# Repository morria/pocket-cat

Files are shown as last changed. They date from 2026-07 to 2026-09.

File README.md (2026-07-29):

# Pocket Cat

Control your HF transceiver from an iPhone. Pocket Cat is a small
BLE↔USB bridge — a Seeed XIAO ESP32-S3 plugged into the radio's USB CAT
port — plus a Swift library (`CATBridgeKit`) that gives iOS apps a typed,
observable model of the rig: frequency, mode, PTT, RF power, a catalog of
rig settings (gains, squelch, keyer speed, NB/NR, preamp, attenuator,
filter width …), and Yaesu menu items, over Bluetooth LE — with raw CAT
kept only as an escape hatch.

Built for portable operation: radios like the FT-891 have full CAT
control but no Bluetooth. Pocket Cat adds it without putting any radio
logic in the firmware.

## Supported radios

| Radio | CAT dialect | USB interface |
|---|---|---|
| Yaesu FT-891 | Yaesu ASCII (`;`-terminated) | CP2105 dual UART |
| Yaesu FTX-1 | Yaesu ASCII (`;`-terminated) | CP210x/CDC (confirmed at bring-up) |
| QRP Labs QMX | Kenwood TS-480 subset | Native CDC-ACM |

## How it works

```
iOS app ──(SwiftUI/@Observable)── CATBridgeKit
                                      │  BLE GATT (bonded, encrypted)
                              XIAO ESP32-S3 bridge
                                      │  USB host (CDC-ACM / CP210x)
                                   radio CAT port
```

**The bridge is a dumb pipe.** The firmware enumerates the radio over USB
host, shuttles bytes between USB and BLE, and exposes a small control
channel (baud, link state, radio identity, failsafe). All CAT protocol
knowledge — command encoding, response parsing, polling, state modeling —
lives in `CATBridgeKit`. New radio support is a Swift change; the firmware
doesn't care.

An app's complete state-and-control loop:

```swift
import CATBridgeKit

let central = CATBridgeCentral()
let bridge = await central.bridges().first { _ in true }!
let session = try await central.connect(to: bridge) // pairs, probes baud,
                                                    // picks dialect, arms failsafe
Text(session.state.frequency?.description ?? "—")   // bind UI to state
try await session.set(frequency: 14_074_000)        // send commands
```

Because the BLE link can key a 100 W transmitter, the release firmware
requires LE Secure Connections bonding before accepting any CAT or control
writes, and a dead-man failsafe drops PTT if the link goes quiet.

## Build one

**[`BUILD.md`](BUILD.md) is the start-to-finish walkthrough** — prerequisites,
what to buy, printing, flashing, soldering, assembly, and installing the app,
with a checkpoint at every stage so you know each step worked before starting
the next. The reference detail lives alongside the thing it describes:

| For | See |
|---|---|
| Parts, tools, and where to buy them | [`BOM.md`](BOM.md) |
| Printing, assembly, adjusting the fit | [`enclosure/README.md`](enclosure/README.md) |
| Firmware build / test / flash | [`esp32s3/README.md`](esp32s3/README.md) |
| FT-891 app build / test / install | [`ios/pocket-cat-ft891`](ios/pocket-cat-ft891) |
| QMX app build / test / install | [`ios/pocket-cat-qmx`](ios/pocket-cat-qmx) |
| FTX-1 app build / test / install | [`ios/pocket-cat-ftx1`](ios/pocket-cat-ftx1) |

A unit is a XIAO ESP32-S3 (the version with the U.FL antenna connector — there
is no onboard antenna), a 602535 LiPo cell, a TPS61023 boost module to feed
5 V back to the radio, an SS12F15G5 slide switch, one M3 bolt and nut, and two
printed parts — about 23 g of PETG. You also need a **USB-to-UART dongle** to
flash, since the XIAO's own USB-C port is occupied by the radio.

The case is IP00: open USB aperture, open switch slot, unsealed parting line.
Bag and bench use.

## The apps

**[FT-891](ios/pocket-cat-ft891)** — operate (frequency, mode, band, meters,
RF power, tuner, split/clarifier, hold-to-talk PTT), all 159 menu items in
plain English, and profiles that capture the radio's full configuration to
iCloud Drive and diff it against the live rig.

**[FTX-1](ios/pocket-cat-ftx1)** — the FT-891 surface extended for a
full-mode SDR: every newcat mode including C4FM and DATA-FM, a CW keyboard
driving the radio's memory keyer, and raw `EX` menu access with your own
bookmarks.

**[QMX](ios/pocket-cat-qmx)** — operate (four modes plus sideband, RIT, split,
keyer), the radio's **entire menu tree** discovered live over the QMX `MM`/`ML`
Menu Manager with a written explanation for every item, and
save/load-everything profiles.

Both include a full simulator, so the whole app runs with no hardware at all.

## Using the library

Add as a Swift Package dependency (iOS 17+ / macOS 14+):

```swift
.package(url: "https://github.com/morria/pocket-cat.git", from: "1.0.0")
```

then `import CATBridgeKit`.

## Repository layout

```
esp32s3/            bridge side
  firmware/         ESP-IDF (≥5.2) project for the XIAO ESP32-S3
  test/host/        C unit + end-to-end simulation suites (gcc, ASan/UBSan)
  test/tools/       radio_sim.py, ble_client.py, soak.py bench tools
  docs/             implementation plan, BLE protocol spec (normative)
Package.swift       Swift package manifest (swift-tools 6.0; iOS 17 / macOS 14)
Sources/            CATBridgeCore (pure logic) + CATBridgeBLE (CoreBluetooth)
Tests/
BUILD.md            start-to-finish build walkthrough
ios/
  pocket-cat-ft891/ FT-891 iOS app — FT891Kit (menu catalog, profiles,
                    simulator) + FT891UI (SwiftUI) + xcodegen app shell
  pocket-cat-qmx/   QMX iOS app — QMXKit (MM/ML menu client, profiles,
                    simulator) + QMXUI (SwiftUI) + xcodegen app shell
  pocket-cat-ftx1/  FTX-1 iOS app — FTX1Kit (Yaesu commands, passband,
                    memories) + FTX1UI (SwiftUI) + xcodegen app shell
BOM.md              bill of materials for one unit
enclosure/          3D-printable case — pocket_cat_case.scad + base/lid STLs,
                    with printing and assembly instructions
docs/               system-level reports + library implementation plan
```

## Testing

```sh
make -C esp32s3/test/host run            # C suites: unit + e2e simulation
python3 -m pytest esp32s3/test/tools -q  # codec, radio_sim, pty rig tests
swift test
```

The BLE wire format is pinned by a golden vector file byte-compared across
the firmware and Swift codebases in CI. Hardware-in-the-loop bench tools
(`radio_sim.py`, `ble_client.py`, `soak.py`) are described in
`esp32s3/docs/implementation.md` §7.

## Status

All layers build and pass CI (ESP-IDF v5.3 target build, 57 C tests,
32 Python tests, 56 Swift tests), and the firmware runs on real XIAO
ESP32-S3 hardware — advertising, bonding policy, and the status channel
verified over the air. Radio bring-up (FT-891 first) is next; see
[`docs/completeness-report.md`](docs/completeness-report.md) for exactly
what is and isn't yet proven on hardware.

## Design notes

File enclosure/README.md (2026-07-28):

# PocketCAT — enclosure

A two-part printed enclosure for a battery-powered Bluetooth-to-CAT
adapter. It holds a Seeed XIAO ESP32S3, a 602535 LiPo cell, a flat FPC
antenna, a slide switch, and a TPS61023 boost module that supplies 5 V to
the USB device attached to the XIAO.

**Closed size: 59.2 × 47.2 × 18.9 mm.** Two printed parts, one bolt, one
nut.

---

## Files

| File | Description |
|---|---|
| `pocket_cat_base.stl` | Base — cell bay, antenna bay, switch mount, bolt boss |
| `pocket_cat_lid.stl` | Lid — board pocket, boost cradle, captive nut boss |
| `pocket_cat_case.scad` | Parametric source, OpenSCAD customizer ready |
| `BOM.md` | Bill of materials |
| `WIRING.md` | Wiring diagrams and connection tables |

The `.scad` is the source of truth; both STLs are generated from it:

```
openscad -o pocket_cat_base.stl -D 'part="base"' pocket_cat_case.scad
openscad -o pocket_cat_lid.stl  -D 'part="lid"'  pocket_cat_case.scad
```

---

## Bill of materials

| Item | Notes |
|---|---|
| Seeed XIAO ESP32S3 | 17.7 × 21.1 mm, USB-C overhanging 2.9 mm |
| 602535 LiPo, 3.7 V 500 mAh | 25 × 37 × 6 mm pouch cell |
| FPC antenna, 37 × 18 mm | With U.FL pigtail |
| SS12F15G5 slide switch | SPDT, 19.8 mm frame, ⌀2.2 holes, 3 × 3 × 5 mm knob |
| TPS61023 boost module | 17.8 × 11.3 mm, header **not** fitted |
| M3 × 10 hex socket head bolt | ×1 |
| M3 nut | ×1 |
| 26 AWG stranded wire | ~60 mm per run |

---

## Layout

The interior is divided lengthwise by a 7 mm rib. Heavy items sit in the
base; the two circuit boards mount to the lid and lift out with it.

**Base, left bay — 27 × 39 × 7.0 mm.** The cell lies flat on the floor
against a backstop rib at the far end. There is 1.0 mm of clearance above
it for pouch swelling; nothing should be packed into that space.

**Base, right bay — 22 × 39 mm.** Empty apart from the slide switch on
its outer wall. The width is set by the span the lid needs for the
antenna, not by anything in the base.

**Base, right wall.** Two slide switches, centred at y 12.6 and y 34.6.
Each has its own peg pair on 14.4 mm centres and a 6.4 × 3.6 mm actuator
slot. S1 is the master on/off; S2 selects run or charge. A local 1.2 mm relief
in the lid skirt above the switch gives the frame room.

The pegs are deliberately unequal. One is round at ⌀1.90; the other is a
lozenge, 2.00 mm across the pitch axis but only 0.90 mm along it. The
round peg locates the switch and the lozenge holds its angle while
letting hole-spacing error float out. Together they absorb **±0.80 mm**
of pitch variation, against the ±5 % (±0.72 mm) these switches are made
to. Both taper at the tip for a square start and have 0.15 mm shaved off
their undersides to compensate for print sag.

**Divider rib.** Carries the bolt boss, and has a notch through its top
edge at each switch centreline, y 12.6 and y 34.6, for the switch
wiring.

**Lid, board pocket — 18.0 × 21.4 mm.** The XIAO sits component-side
down, USB-C pointing into the wall aperture. Two ramped tabs per side
retain it. The whole pocket floor is relieved 1.2 mm, giving 2.8 mm of
clearance over the BAT+/BAT− solder joints.

**Lid, wire channel.** A 3.0 mm gap through both pocket ribs at
y 12.6–15.6, with a matching groove in the lid, forms a 2.6 mm tall route
for the battery leads to leave the board pocket. Cut on both sides — use
whichever suits your pad positions.

**Lid, boost cradle — 18.8 × 12.3 mm.** Ribs 1.6 × 2.5 mm locate the
module on all four sides, with a 10 mm opening in the pad edge for
soldering access and a 0.5 mm lead-in chamfer at the mouth. The ribs are
a deliberately loose fit — 0.5 mm per side — so the module drops in
squarely. The bay clears modules up to 7.5 mm thick.

A compliant retention finger at each end snaps the module down. Each is
1.0 mm thick, hangs 4.2 mm below the lid and sits in its own relief slot
so it flexes independently. They stand at the board's nominal edge rather
than at the rib, so clearance and grip are set separately: the ribs stay
loose for easy insertion while the fingers alone do the holding.

The retaining face is a **wedge rather than a square shoulder**, so it
grips any PCB from 0.6 to 1.8 mm thick without knowing the thickness in
advance. Overlap onto the board is 0.21 mm at 1.0 mm thickness, 0.39 at
1.2 and 0.76 at 1.6. The finger's spring preloads the module against the
lid.

**Lid, boost-to-board channels.** Two 3.5 mm openings through the pocket
end stop at x 10.6–14.1 and 16.1–19.6, separated by a 2 mm web. They cut
below the board only (z 10.7–13.3), so the stop stays solid at board
level and still blocks the PCB's rear edge. These carry the boost 5V and
GND leads into the pocket; the web keeps the pair separated.

The battery-to-boost run needs no channel — the space between the cell
top and the lid is open the whole way, and the leads rise straight into
the cradle's 10 mm pad-edge gap.

**Lid, antenna recess — 18.4 × 37.4 × 0.4 deep.** The FPC adheres to the
lid inner face, in a shallow recess between the nut boss and the skirt.
Mounting it here rather than in the base keeps the whole RF path on one
part: the pigtail never crosses the parting line, so opening the case
does not flex the U.FL connector. It also puts the switch frame 7 mm
below the antenna instead of 1.1 mm above it.

**Lid, pigtail exit.** A full-height gap through both pocket ribs at
y 20.9–23.5, at the far end of the board from the USB-C. It runs below
the board only, so the lid keeps full thickness there. Two ⌀1.8 guide
posts at x 34.0 form a 1.6 mm channel carrying the pigtail past the nut
boss on its way to the antenna.

**Lid, wire anchors.** Two ⌀2.0 posts hanging 4.0 mm from the lid form a
**3.6 mm channel**, set 0.65 mm clear of the board pocket rib, sized for two 22 AWG silicone leads side by side.
They take strain off the BAT+/BAT− pads, which are surface pads with no
through-hole anchorage and lift if a lead is pulled.

---

## Fastener

A single M3 enters from the **underside**, its head fully recessed in a
⌀6.2 × 3.0 counterbore flush with the bottom face. It passes up through a
stub on the divider rib and threads into a nut held captive in a boss
under the lid. Nothing protrudes from either outer face.

The nut pocket sits at z 10.6–13.1 with 3.0 mm of material above it and
loads through a slot on the antenna-bay side. An M3 × 10 engages 2.4 mm
of thread; an M3 × 12 also fits.

Tighten snug only. The skirt engages 7.5 mm around the full perimeter and
carries the shear; the bolt only resists lift.

---

## Key dimensions

| Feature | Value |
|---|---|
| Cell bay | 27 × 39 × 7.0 mm |
| Antenna recess (lid) | 18.4 × 37.4 × 0.4 deep |
| Board pocket | 18.0 × 21.4 mm |
| Clearance over BAT pads | 2.8 mm |
| USB-C aperture | 9.6 × 3.8 mm, at z 9.8–13.6 |
| Switch slot | 6.42 × 3.62 mm |
| Panel markings | 3.5 mm tall (triangle 4.4), 0.9 stroke, 0.5 deep |
| Wire anchor channel | 3.6 mm wide × 4.0 deep |
| Pigtail exit gap | y 20.9–23.5, full rib height |
| Pigtail guide channel | 1.6 mm |
| Boost-to-board channels | 2 × 3.5 mm, below the board |
| Peg pitch | 14.4 mm, ±0.80 mm absorbed, 2 pairs |
| Boost cradle | 18.8 × 12.3 mm, 7.5 mm depth clearance |
| Boost PCB grip range | 0.6 – 1.8 mm |
| Wall / floor / lid | 1.6 / 1.6 / 2.8 mm |

---

## Printing

- PETG, 0.4 mm nozzle, 0.2 mm layer, 4 walls, 25 % infill
- **No supports.** The USB aperture is split across the parting line, and
  every hole either opens downward or bridges under 18 mm.
- Base prints floor down; lid prints top face down, as exported
- The switch pegs print as horizontal features and sag slightly on their
  undersides. Dress them with a blade before fitting the switch.

---

## Assembly

**Prepare**

1. Clean the two switch pegs until the frame drops on without forcing.
   Take material off the undersides first — that is where sag collects.
2. Slide the M3 nut into the lid boss through the slot on the
   antenna-bay side. A dab of glue makes it permanent.

**Base**

3. Fit the slide switch onto the posts, actuator through the slot, and
   glue.
4. Lay the cell in the left bay against its backstop. Do not glue it, and
   do not fill the 1.0 mm space above it. If it rattles, lay a strip of
   Kapton across it and stick that to the bay walls, not to the pouch.

**Lid**

6. Wipe the lid antenna recess with IPA and adhere the FPC. PETG is a
   poor adhesive substrate — abrade it lightly if the bond feels weak.
7. Fit the XIAO: connector into the aperture first, then press the rear
   edge up past the retention ramps.
8. Route the U.FL pigtail out of the board pocket through the gap at
   y 20.9–23.5 and through the guide posts at x 34.
9. Press the boost module into its cradle with the pad edge facing the
   board, until both end fingers snap over it.

**Wiring** — work with the halves side by side, and allow **60 mm** per
run so the lid can lie flat during service.

9. Cut the JST plug off the cell. Solder its leads to BAT+ and BAT− on
   the underside of the XIAO, bend the wires flat immediately, and put a
   blob of hot glue over the joint. Those pads lift if a wire is tugged.
10. Wire cell + to the switch common, and the switched output to both the
    XIAO BAT+ and the boost Vin. Switching off then kills the boost as
    well, so its output cannot fight a host's VBUS when a PC is plugged
    into the USB-C port to reflash.
11. Wire cell − to boost GND.
12. Wire boost 5V and GND to VUSB and GND on the XIAO, passing them
    through the two channels in the end stop — one lead per channel.
    Twist both the input and output pairs tightly; loop area is what
    radiates.
13. Check whether En has a pull-up on your boost module. If not, tie it
    to Vin.

**Close**

14. Dress the battery leads out through the wire channel and hook them
    through the anchor posts.
15. Route the boost leads forward along the gap at x 25.3–28.6 to reach
    the wire channel.
16. Lower the lid — the skirt slides inside the base walls — then fit the
    M3 from underneath and snug it.

---

## Adjusting the fit

Open the `.scad` in OpenSCAD and use View → Customizer. Everything is a
named parameter.

| If | Change |
|---|---|
| The lid is tight or loose | `skirt_gap` |
| The board is tight or loose | `pcb_fit_x`, `pcb_fit_y` |
| The board needs more or less retention | `lip` |
| The switch pegs are tight or loose | `post_d`, `post2_d`, in 0.05 steps |
| The pegs will not reach both holes | `post2_y` — narrower absorbs more |
| The switch actuator binds | `sw_travel` — set to your measured throw |
| The on/off markings are the wrong way round | `mark_flip` |
| The switch sits high or low | `sw_cz` |
| The cell measures over 6 mm | `bat_z`, or `bat_swell` for headroom |
| The boost module is a different size | `boost_l`, `boost_w` |
| The boost fingers grip loosely or not at all | `boost_wedge`, `boost_tab_off` |
| The boost pocket is tight or loose | `boost_fit` |
| The wire anchors are tight for your gauge | `anchor_gap`, `anchor_h` |
| The U.FL sits at the other end of the board | `coax_y0`, `coax_y1` |
| The boost-to-board channels are tight | `endch_w`, `endch_gap` |

---

## Limitations

No gasket, an open USB aperture, an open switch slot, an unsealed parting
line: this is IP00. Bag and bench use only.

The switch frame and the boost module both sit above the antenna bay
region, and the case has no shielding. If the boost's switching noise
raises your HF noise floor, fit a ferrite on the USB lead and consider
lining the lid over the boost with copper tape bonded to battery
negative.

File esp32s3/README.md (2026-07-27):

# Pocket Cat — ESP32-S3 BLE↔USB CAT Bridge

Pocket Cat firmware for a Seeed XIAO ESP32S3 that bridges a BLE central (iOS app) to a
transceiver's USB CAT interface (Yaesu FT-891, Yaesu FTX-1, QRP Labs QMX).
The ESP32 is a transparent byte pipe; all CAT protocol logic lives on the
remote. See [`docs/implementation.md`](docs/implementation.md) for the full
design and [`docs/protocol.md`](docs/protocol.md) for the BLE contract.

## Layout

```
firmware/            ESP-IDF (≥5.2) project
  main/              app wiring, bridge task, LED
  components/
    ctrl_proto/      BLE control-channel TLV codec       (pure C, host-tested)
    cat_bridge/      rings, coalescer, detect, core      (pure C, host-tested)
    usb_link/        usb_host + CDC-ACM/CP210x glue
    ble_link/        NimBLE GATT server
test/
  host/              unit + end-to-end simulation suites (gcc + ASan/UBSan)
  tools/             radio_sim.py, ble_client.py, soak.py, catproto.py
docs/                implementation plan, protocol spec, references/
```

## Prerequisites

- **ESP-IDF ≥ 5.2** (CI builds against 5.3) — install per
  [Espressif's getting-started guide](https://docs.espressif.com/projects/esp-idf/en/stable/esp32s3/get-started/).
  Every new shell needs `. $HOME/esp/esp-idf/export.sh`.
- **Python 3** with `pytest pytest-timeout pyserial`, for the tools tests.
- **A USB-to-UART dongle with 3.3 V logic** (CP2102, CH340, FT232) to flash.
  A 5 V-only dongle will damage the board.

Verify with `idf.py --version`.

## Build

```sh
cd firmware
idf.py set-target esp32s3      # once per checkout
idf.py build
```

## Test

Both suites are host-side and need no hardware:

```sh
make -C test/host run              # C: unit + e2e simulation (ASan/UBSan)
python3 -m pytest test/tools -q    # Python: codec, radio_sim, pty rig
```

Both must exit 0. CI runs exactly these on every push.

## Flash

**The native USB-C port cannot be used for flashing** — it runs in host mode
for the radio. Console and bootloader are on UART0, so wire the dongle to the
board first. Note that TX goes to RX:

| Dongle | XIAO ESP32-S3 |
|---|---|
| TX | GPIO44 (RX) |
| RX | GPIO43 (TX) |
| GND | GND |

```sh
idf.py -p /dev/tty.usbserial-XXXX flash monitor    # macOS
idf.py -p /dev/ttyUSB0 flash monitor               # Linux
```

Find the port with `ls /dev/tty.usb*` or `ls /dev/ttyUSB*`. If flashing won't
start, hold **BOOT**, tap **RESET**, release BOOT to enter the ROM downloader,
then run the command again.

Flash **before** the board goes into the enclosure — it mounts component-side
down and the pads become awkward to reach (see [`../BUILD.md`](../BUILD.md)).

VBUS must be supplied to the radio — measure the 5V↔VBUS net first
([`docs/references/hardware-xiao-esp32s3.md`](docs/references/hardware-xiao-esp32s3.md)).

Debug build without BLE bonding (bench only — LED triple-blinks):
`idf.py menuconfig` → CAT Bridge BLE → uncheck "Require LE encryption".

**Working:** `idf.py monitor` shows the bridge booting and it advertises as
`CATBridge-XXXX` in any BLE scanner.

Hardware-in-the-loop (docs §7.3/§7.4): run `radio_sim.py` on a CP2105/CP2102/
CDC fixture attached to the ESP32's USB port, and drive BLE with
`ble_client.py` (`status`, `cat "FA;"`, `echo`, `storm`) and `soak.py`.
CI builds the firmware (ESP-IDF v5.3) and runs every host suite on each push.

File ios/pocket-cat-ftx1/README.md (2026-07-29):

# Pocket Cat FTX-1

Native iOS control for the Yaesu FTX-1 over the [Pocket Cat](../..) BLE↔USB
CAT bridge. SwiftUI, iOS 17+.

- **Operate** — frequency (digit-drag tuning, direct entry), full mode set,
  band bar with band-stacking, S/PO/SWR/ALC meters, RF power, antenna-tuner
  cycle, split/clarifier/VFO ops, the passband strip, hold-to-talk PTT
  (failsafe-interlocked).
- **CW** — type and the radio's memory keyer sends it, with station
  templates and an on-air time estimate.
- **Menu** — raw `EX` access by number, with bookmarks you build yourself.
- **Memories** — saved channels and automatic recents, kept on the device.

A built-in simulator (Connection → Simulated FTX-1) runs the whole app with
no hardware.

Built from the [FT-891 app](../pocket-cat-ft891): the FTX-1 speaks the same
modern Yaesu ASCII dialect, so the operate surface, passband strip, band
memories and connection plumbing carry straight over
(`esp32s3/docs/references/yaesu-cat-ftx1.md`).

## What differs from the FT-891 app

- **Full mode set.** The FTX-1 is a full-mode SDR, so the newcat codes the
  FT-891 leaves unused are live: `A` DATA-FM, `E` C4FM, `F` DATA-FM-N.
- **CW keyboard.** Send-only, and the screen says so — a Yaesu has no
  command that hands decoded CW back, which is why the QMX app has a live
  transcript and this doesn't.
- **Menu by number, not by catalog.** The FT-891 app ships a typed catalog
  of its 159 items. The FTX-1's numbering differs and this repo has no
  verified catalog for it, so the Menu tab reads and writes raw `EX` digits
  and lets the radio judge them. A borrowed catalog would confidently write
  the wrong setting.
- **No profiles yet.** Capture/diff/apply is built on that catalog, so it
  returns when there is one.

## Layout

```
Package.swift        FTX1Kit (radio semantics) + FTX1UI (SwiftUI)
Sources/FTX1Kit/     command wrappers, passband, band memories, CW text and
                     timing, station settings, simulator, RigController
Sources/FTX1UI/      Operate / CW / Menu / Connection views
App/                 xcodegen shell (project.yml) for the iOS app target
Tests/FTX1KitTests/  sim-driven integration, passband, memories
```

## Prerequisites

Xcode 15+, and `xcodegen` (`brew install xcodegen`) to generate the app
project. Nothing else to clone: this package lives inside the Pocket Cat
repo at `ios/pocket-cat-ftx1` and depends on the root package
(`CATBridgeKit`) by the relative path `../..`.

## Test

```sh
swift test          # headless: FTX1Kit + full sim integration, no hardware
```

## Build and run

```sh
cd App && xcodegen generate      # creates FTX1.xcodeproj
open FTX1.xcodeproj              # run the FTX1App scheme
```

Set your own signing team in Xcode (target → Signing & Capabilities); find
the ID with:

```sh
security find-certificate -c "Apple Development" -p |
  openssl x509 -noout -subject | tr ',' '\n' | grep OU
```

## Install on a device

```sh
xcrun devicectl list devices
xcodebuild build -project FTX1.xcodeproj -scheme FTX1App \
  -destination 'id=YOUR-DEVICE-ID' -derivedDataPath build \
  -allowProvisioningUpdates
xcrun devicectl device install app --device YOUR-DEVICE-ID \
  build/Build/Products/Debug-iphoneos/FTX1App.app
```

If signing fails on the iCloud entitlement, build with
`CODE_SIGN_ENTITLEMENTS=FTX1App/FTX1App-NoCloud.entitlements`.

## Not yet confirmed on hardware

The FTX-1 has not been through bring-up. Per
`esp32s3/docs/references/yaesu-cat-ftx1.md` its USB descriptor **is**
confirmed — a CP2105 behind an internal hub — but its `ID;` response code is
not, and neither is which of the dual UARTs is Enhanced. The app works
through the bridge's generic Yaesu profile regardless.

The passband strip's `IS`/`SH`/`BP`/`CO` formats are inherited from the
FT-891 family rather than verified on an FTX-1, and the simulator answers
`ID;` with the FT-891's code as a placeholder. Both want checking against a
real rig before they are trusted.

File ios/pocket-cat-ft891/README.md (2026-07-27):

# FT-891 Pocket

Native iOS control for the Yaesu FT-891 over the
[Pocket Cat](../..) BLE↔USB CAT bridge. SwiftUI, iOS 17+.

- **Operate** — frequency (digit-drag tuning, direct entry), mode, band,
  S/PO/SWR/ALC meters, RF power, antenna-tuner cycle, split/clarifier/VFO
  ops, hold-to-talk PTT (failsafe-interlocked).
- **Settings** — all 159 FT-891 menu items with plain-English names and
  descriptions, searchable, editable over CAT (`EX`).
- **Profiles** — capture the radio's full configuration to a JSON file in
  iCloud Drive; diff any profile against the live radio and apply the
  changes with per-item confirmation.

A built-in FT-891 simulator (Connection → Simulated FT-891) runs the whole
app with no hardware.

## Layout

```
Package.swift        FT891Kit (radio semantics) + FT891UI (SwiftUI)
Sources/FT891Kit/    menu catalog (159 items), FT-891 command wrappers,
                     profile engine/store, simulator transport, RigController
Sources/FT891UI/     Operate / Settings / Profiles / Connection views
App/                 xcodegen shell (project.yml) for the iOS app target
Tests/               codecs, catalog↔docs checker, sim-driven integration
docs/                CAT + menu references, research, fun-feature backlog
PLAN.md              design/implementation/test plan
```

## Prerequisites

Xcode 15+, and `xcodegen` (`brew install xcodegen`) to generate the app
project. Nothing else to clone: this package lives inside the Pocket Cat
repo at `ios/pocket-cat-ft891` and depends on the root package
(`CATBridgeKit`) by the relative path `../..`.

## Test

```sh
swift test          # headless: FT891Kit + full sim integration, no hardware
```

## Build and run

```sh
cd App && xcodegen generate      # creates FT891.xcodeproj
open FT891.xcodeproj             # run the FT891App scheme
```

Regenerate whenever `project.yml` changes; the `.xcodeproj` is not tracked.

Set your signing team in Xcode (target → Signing & Capabilities). Find your
team ID with:

```sh
security find-certificate -c "Apple Development" -p |
  openssl x509 -noout -subject | tr ',' '\n' | grep OU
```

Run the **Simulated FT-891** connection first — the entire app works against
the built-in simulator with no bridge and no radio.

## Install on a device

From Xcode: select your iPhone and run. From the command line:

```sh
xcrun devicectl list devices          # find the device identifier
xcodebuild build -project FT891.xcodeproj -scheme FT891App \
  -destination 'id=YOUR-DEVICE-ID' -derivedDataPath build \
  -allowProvisioningUpdates DEVELOPMENT_TEAM=YOURTEAMID
xcrun devicectl device install app --device YOUR-DEVICE-ID \
  build/Build/Products/Debug-iphoneos/FT891App.app
```

The device must be unlocked and have Developer Mode enabled.

**If signing fails on the iCloud entitlement** — *"provisioning profile
doesn't match the entitlements file's values for
`com.apple.developer.ubiquity-container-identifiers`"* — your team has no
iCloud container for this bundle ID. Either create one (Xcode → target →
Signing & Capabilities → **+ Capability** → iCloud), or build without it:

```sh
CODE_SIGN_ENTITLEMENTS=FT891App/FT891App-NoCloud.entitlements
```

Profiles then save on-device instead of to iCloud Drive; everything else is
unaffected.

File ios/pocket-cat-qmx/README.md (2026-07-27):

# Pocket Cat QMX

An iOS rig controller for the **QRP Labs QMX** through a Pocket Cat
bridge: frequency, the QMX's four modes plus sideband, RIT, split, keyer
speed, live meters — and **the radio's entire configuration menu**,
discovered live over the QMX's `MM`/`ML` Menu Manager CAT commands, with
a written explanation for every item the catalog knows.

Because discovery is live, the menu screen always matches the connected
firmware: items this app has never heard of still appear and edit
correctly (with a generic note) — `QMXMenuNotes` just hasn't written them
up yet.

Profiles capture **everything** — every menu leaf (including per-band
grid cells) plus operating state — into a `.qmxjson` file in iCloud
Drive, and apply writes back only what differs, with per-item read-back
verification. QMX `MM` writes persist to the radio's EEPROM.

Layout mirrors `../pocket-cat-ft891`:

```
Sources/QMXKit/     RigController, QMX command wrappers (Q1/RIT/SP/meters),
                    MM/ML menu client + explanations, profiles, simulator
Sources/QMXUI/      SwiftUI: Operate / Menu / Profiles
App/                xcodegen shell (cd App && xcodegen generate)
Tests/QMXKitTests/  swift-testing: protocol units + sim-driven integration
```

Wire formats follow the *QMX CAT programming manual* fw 1_02_006
(`esp32s3/docs/references/qmx-cat.md`). Notable QMX facts the app
respects: `PC` is a **get-only power meter in tenths of a watt**, `SM`
reads dB, `MD` accepts only CW/DIGI/CW-R/FSK-R (sideband is `Q1`), and
the two-letter commands are session-only while `MM` writes persist.

## Prerequisites

Xcode 15+, and `xcodegen` (`brew install xcodegen`). The package depends on
the root Pocket Cat package (`CATBridgeKit`) by the relative path `../..`, so
a plain checkout is all you need.

## Test

```sh
swift test          # QMXKit + sim-driven integration, no hardware
```

## Build and run

```sh
cd App && xcodegen generate      # creates QMX.xcodeproj
open QMX.xcodeproj               # run the QMXApp scheme
```

The connection sheet includes a **Simulated QMX** — the entire app runs
against the built-in simulator with no hardware. Start there.

**`App/project.yml` has a `DEVELOPMENT_TEAM` baked in — replace it with
yours**, or device builds will fail to sign. Find your team ID with:

```sh
security find-certificate -c "Apple Development" -p |
  openssl x509 -noout -subject | tr ',' '\n' | grep OU
```

## Install on a device

```sh
xcrun devicectl list devices          # find the device identifier
xcodebuild build -project QMX.xcodeproj -scheme QMXApp \
  -destination 'id=YOUR-DEVICE-ID' -derivedDataPath build \
  -allowProvisioningUpdates
xcrun devicectl device install app --device YOUR-DEVICE-ID \
  build/Build/Products/Debug-iphoneos/QMXApp.app
```

The device must be unlocked with Developer Mode enabled.
`-allowProvisioningUpdates` also registers the app's iCloud container the
first time, which profile sync needs. If signing still fails on the iCloud
entitlement, add the capability in Xcode (target → Signing & Capabilities →
**+ Capability** → iCloud) — or strip it as the FT-891 app does with its
`FT891App-NoCloud.entitlements`, at the cost of falling back to on-device
profile storage.

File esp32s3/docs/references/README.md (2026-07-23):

# Reference Documentation

Curated, offline reference material for building the ESP32-S3 BLE↔USB CAT
bridge. These documents distill the authoritative sources into the specific
facts the firmware and the iOS app need, so implementers don't have to re-derive
CAT formats, USB IDs, or pinouts mid-task.

## What's here

| File | Covers |
|---|---|
| [`yaesu-cat-ft891.md`](yaesu-cat-ft891.md) | FT-891 CAT command set, serial format, IF/FA/MD field layouts |
| [`yaesu-cat-ftx1.md`](yaesu-cat-ftx1.md) | FTX-1 CAT notes, USB dual-CP210x enumeration, deltas vs FT-891 |
| [`qmx-cat.md`](qmx-cat.md) | QMX CAT (Kenwood TS-480 subset), mode codes, KY keying, quirks |
| [`hardware-xiao-esp32s3.md`](hardware-xiao-esp32s3.md) | XIAO ESP32S3 pinout, USB-OTG host mode, VBUS/power, console/flash |
| [`usb-cp210x-cdc.md`](usb-cp210x-cdc.md) | CP2102/CP2105 & CDC-ACM USB descriptors, VID/PID, interface map |
| [`firmware-esp-idf-usb-host-vcp.md`](firmware-esp-idf-usb-host-vcp.md) | ESP-IDF USB Host stack + esp-usb VCP drivers, lifecycle, line coding |
| [`firmware-nimble-ble.md`](firmware-nimble-ble.md) | NimBLE peripheral/GATT reference for the BLE link |

## How these were verified

The CAT command tables (especially mode codes) were cross-checked against
**Hamlib** (the reference open-source rig-control library, `Hamlib/Hamlib` on
GitHub) so the byte-level formats are grounded in a working implementation, not
just recollection:

- Yaesu `MD` mode codes: `rigs/yaesu/newcat.c` → `newcat_mode_conv[]`.
- FT-891 serial defaults (4800–38400): `rigs/yaesu/ft891.c`.
- Kenwood/QMX `MD` mode codes: `rigs/kenwood/kenwood.c` → `kenwood_mode_table[]`.

## Canonical primary sources (download these too)

These are the manufacturer documents of record. **They are hosted on sites the
session's network egress policy blocks, so they could not be auto-downloaded
into this folder** — grab them from a normal browser and drop the PDFs beside
these notes (add them to `.gitignore` if you'd rather not commit binaries):

- **FT-891 CAT Operation Reference Book** — Yaesu.
  `https://www.rigpix.com/yaesu/ft891_cat_manual.pdf` (mirror), or
  ManualsLib / the Yaesu Files portal.
- **FT-891 Advance / Operating Manual** — Yaesu (menu `05-06 CAT RATE`, etc.).
- **FTX-1 Series CAT Operation Reference Manual** — Yaesu (needs MAIN firmware
  ≥ 1.08). Search "FTX-1 CAT Operation Reference Manual".
- **QMX CAT reference** — QRP Labs:
  `https://qrp-labs.com/images/qmx/manuals/cat_1_02_006.pdf`.
- **Kenwood TS-480 PC Control Command reference** — Kenwood
  (`ts_480_pc.pdf`); the parent spec QMX borrows from.
- **ESP32-S3 Technical Reference Manual** & **datasheet** — Espressif
  (USB-OTG / USB-Serial-JTAG chapters).
- **ESP-IDF USB Host docs** & **esp-usb** component registry — Espressif
  (`docs.espressif.com`, `components.espressif.com`, `github.com/espressif/esp-usb`).
- **XIAO ESP32S3 wiki & schematic** — Seeed Studio (`wiki.seeedstudio.com`).
- **CP210x / CP2105 datasheets & AN571 (USB descriptors)** — Silicon Labs.

> Provenance note: the tables below are engineering references compiled for this
> project. Where a value is safety- or interop-critical (mode codes, VID/PID,
> the CP2105 CAT interface index), verify once against the primary PDF and the
> real radio during bring-up before freezing it — see the acceptance checklist
> in `../implementation.md` §7.5.

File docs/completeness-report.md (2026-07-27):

# Completeness Report — CAT Bridge System

**Date:** 2026-07-24 · **Scope:** everything on `main` (`f5c4ccf`)
**Question under investigation:** can an iOS app, using our library, easily
read state from and send commands to each of our three target transceivers
(FT-891, FTX-1, QMX) through the ESP32-S3 BLE bridge?

## 1. Executive answer

**Yes, to the strongest level verifiable without hardware — with one radio
(FTX-1) explicitly provisional and all physical-layer claims awaiting bench
bring-up.**

Every layer of the stack exists, builds, and passes its tests in CI: the
ESP32-S3 firmware (compiled for the real target by ESP-IDF v5.3), the
Python bench tools, and the Swift package (`CATBridgeKit`). The iOS library's
*full* connect → identify → poll → command → PTT → failsafe → reconnect
lifecycle runs against scripted FT-891, FTX-1, and QMX radios in 56 Swift
tests, wire-compatible with the firmware by construction (a shared golden
vector file is byte-compared across both codebases in CI).

What no amount of simulation can prove: the system has **never touched a
real radio, a real XIAO board, or a real iPhone**. Section 5 ranks exactly
which assumptions are load-bearing.

## 2. The "easily" test — what an app actually writes

The complete state-and-control loop for any of the three radios:

```swift
import CATBridgeKit

let central = CATBridgeCentral()                    // one per app
let bridge = await central.bridges().first { _ in true }!
let session = try await central.connect(to: bridge) // scans, pairs, probes
                                                    // baud, picks dialect,
                                                    // arms failsafe — done

// State: bind SwiftUI directly to the @Observable object…
Text(session.state.frequency?.description ?? "—")
// …or consume value snapshots anywhere:
for await snap in await session.snapshots() { … }

// Commands:
try await session.setFrequency(.megahertz(14.250))
try await session.setMode(.cw)
try await session.transmit()   // failsafe-interlocked
try await session.receive()
```

The app never sees BLE UUIDs, TLV frames, CAT dialects, baud rates, `;`
terminators, or retry policy. Radio differences surface only through
`session.capabilities` (e.g. the QMX correctly reports no S-meter and no RF
power control) and `state.radio`. This meets the plan's bar for "any iOS app
should be able to interact with this library."

## 3. Per-radio completeness

| Capability | FT-891 | QMX | FTX-1 |
|---|---|---|---|
| Detected via bridge `radio_id` | ✅ CP2105 `0xEA70` | ✅ CDC-ACM class | ✅ generic CP210x (by design) |
| Identity confirmed via `ID;` | ✅ `ID0650;` | ✅ `ID020;` | ⚠️ placeholder `ID0800;` — real code unknown until hardware |
| Baud negotiation | ✅ 38400→9600→4800 walk, incl. factory-default-4800 case | ✅ skipped (native USB, correctly) | ✅ walk (assumed CP210x) |
| Read frequency / mode / PTT / meter | ✅ (9-digit FA, MD0, TX;, SM0) | ✅ (11-digit FA, MD, IF-flag PTT — `TX;` correctly never polled) | ⚠️ Yaesu dialect assumed |
| Set frequency / mode | ✅ | ✅ | ⚠️ assumed |
| PTT with failsafe interlock | ✅ `TX1;`/`TX0;` | ✅ `TX;`/`RX;` | ⚠️ assumed |
| Keyer text | ✅ `KY` | ✅ `KY ` (untested against sim) | ⚠️ assumed |
| Verified against | scripted personality | scripted personality | *placeholder* personality |

The FTX-1 column is honest engineering posture, not an oversight: the radio's
USB identity and `ID;` code are unconfirmable without hardware (firmware plan
open question #1). The design isolates that risk — `YaesuDialect` is
parameterized, the detect table routes unknown CP210x devices to it, and a
generic-ID fallback (`RadioModel.generic`) keeps an unrecognized Yaesu usable.

## 4. Verification matrix — what is proven, and at what level

| Layer | Proof level | Evidence |
|---|---|---|
| Wire format (CTRL TLV + STATUS) | **Cross-implementation, byte-exact** | one golden JSON, consumed by pytest (55 ✅) + Swift tests, `cmp`'d in CI |
| Firmware logic (rings, coalescer, detect, bridge core) | **Host-tested + simulated e2e** | 57 C tests under ASan/UBSan incl. byte-perfect transparency journaling, failsafe, overflow, 1000-cmd soak |
| Firmware compile for esp32s3 | **CI-built, artifact produced** | ESP-IDF v5.3 job green |
| iOS core (codec, dialects, demux, session actor) | **Unit + integration-simulated** | 56 Swift tests: mode-table matrices, demux fuzz, 21 session tests incl. kill-app-mid-PTT → firmware-failsafe unkey, reconnect + re-arm, cancellation, `?;`-busy |
| iOS BLE adapter | **Compiles (macOS + iOS simulator) + 3 constant/shape tests** | thinnest layer, weakest coverage — by design, but see §5 |
| Anything on physical hardware | **Nothing** | no radio, XIAO, or iPhone has been connected |

Supporting invariants that hold end-to-end in simulation: byte-perfect
transparency (the bridge never corrupts the stream), exactly-one-reply CTRL
semantics, arm-before-key failsafe ordering (journal-proven on both the C and
Swift sides), and stale-data protection (late-reply discard, BLE-absent purge).

## 5. Gaps, ranked by risk

**Blocking real-world use (hardware bring-up items — all pre-documented):**

1. **VBUS power path** on the XIAO (esp32s3 refs): measure `5V`↔VBUS before
   anything else; a bus-powered CP2105 that never enumerates is the #1 trap.
2. **CP2105 Enhanced-interface assumption** (`RD_FT891_CAT_IFACE = 0`): if CAT
   is actually on the other UART, the FT-891 silently doesn't answer.
3. **Yaesu/Kenwood `IF;` field offsets**: parsers match our simulators, which
   match our documentation — but not yet a real rig. A shifted offset breaks
   mode/PTT display (not safety; PTT-off paths don't depend on IF).
4. **FTX-1 identity end-to-end** (USB descriptor, `ID;`, dialect deltas).
5. **iOS pairing/bonding UX** against the firmware's encryption requirement,
   and background-mode behavior — CoreBluetooth is only lightly fake-tested.

**Missing deliverables promised by the plan (non-blocking):**

6. `docs/api-guide.md` (plan M4; `iOS/docs/` at the time of this report) — not written.
7. **DocC catalog** (plan §2) — public symbols have doc comments, but no
   `.docc` bundle or tutorial; the CI DocC step was never added.
8. **Example app / compiling SwiftUI snippet** (M4 acceptance) — none.
9. `swift package diagnose-api-breaking-changes` baseline — deferred until a
   v0.1 tag exists (plan M7), which it doesn't yet.

**Known compromises (acceptable, documented):**

10. BLE adapter tests are 3 shape checks, not the delegate-order fakes the
    plan sketched (§9.3) — the layer is thin and simulator-compile-checked,
    but a regression in, say, notify-subscription ordering would only show on
    hardware.
11. Swift personalities duplicate `radio_sim.py` (drift surfaces on the bench
    rig, which runs the Python originals).
12. `ManualClock.pump` relies on generous task-yielding; theoretically
    schedule-sensitive, empirically stable in CI so far.

## 6. Milestone scorecard

**Firmware plan (M0–M8):** M0–M5 complete to their non-hardware acceptance
criteria (M5's bonding config is implemented and compiled; its BLE test cases
need the bench). M6–M8 (real-radio acceptance, FTX-1, soak/RF) are
hardware-gated by definition.

**iOS plan (M0–M7):** M0–M3 complete. M4 partial (BLE transport ✅ +
simulator build ✅; api-guide ✗, fuller adapter tests ✗). M5–M6 hardware-gated.
M7 (DocC tutorial, API baseline, v0.1 tag) not started.

## 7. Bottom line and recommended next steps

The software is done to the edge of what software alone can prove: **a
developer can add one SPM dependency and, in ~15 lines, observe and control
an FT-891 or QMX through the bridge — with the FTX-1 expected to work and
designed to degrade gracefully if its identity differs.** Every safety
property we could encode (failsafe ordering, PTT interlock, watchdog) is
enforced in code and locked by tests on both sides of the BLE link.

In order:

1. **Bench bring-up** (highest information per hour): flash the XIAO, run
   `radio_sim.py` on a CP2102, drive with `ble_client.py` — this validates
   the entire BLE+USB path with zero radios. Then the CP2105 eval board, then
   real radios per the acceptance checklists.
2. Close the cheap plan debts: api-guide.md, DocC catalog + CI step, a
   minimal SwiftUI example app (doubles as the manual-QA harness for #1's
   iOS leg).
3. After the first green bench pass: tag firmware + library v0.1, wire the
   API-breaking-changes baseline.
4. FTX-1 bring-up when hardware is available; expect only the ID table and
   possibly IF offsets to change.

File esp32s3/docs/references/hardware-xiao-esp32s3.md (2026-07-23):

# Seeed Studio XIAO ESP32S3 — Hardware Reference

Board notes relevant to running the ESP32-S3 as a **USB host** for the radio's
CAT interface. See `../implementation.md` §2 for the design-level treatment;
this is the pin/electrical cheat sheet.

> Sources: Seeed XIAO ESP32S3 wiki & schematic (`wiki.seeedstudio.com`),
> Espressif ESP32-S3 datasheet / Technical Reference Manual (USB-OTG chapter).
> `wiki.seeedstudio.com` is egress-blocked in this session — verify pin numbers
> against the schematic PDF at bring-up.

## SoC

- **ESP32-S3** (dual-core Xtensa LX7 @ up to 240 MHz), Wi-Fi + BLE 5.0 (LE).
- 8 MB flash, 8 MB PSRAM on the XIAO ESP32S3 module.
- Two USB-capable peripherals:
  - **USB-OTG (full-speed, 12 Mbps)** — can be host or device. **This is what we
    use in host mode** to talk to the radio.
  - **USB-Serial-JTAG** — console/JTAG; shares the same physical D+/D− pads as
    USB-OTG on the ESP32-S3, so when OTG host mode owns the port, the
    Serial-JTAG console is unavailable (hence UART0 console, below).

## USB / native-USB pins

| Signal | GPIO | Note |
|---|---|---|
| USB D− | **GPIO19** | routed to the USB-C connector |
| USB D+ | **GPIO20** | routed to the USB-C connector |

In host mode the firmware drives these via the ESP-IDF `usb_host` stack. The
XIAO exposes no separate host connector — **the same USB-C port** is the host
port, so a USB-C→USB (OTG) adapter connects the radio.

## Power / VBUS — the #1 enumeration trap

A bus-powered USB device (e.g. the FT-891's CP2105) draws its 5 V *from the
host* over VBUS. In host mode the XIAO must therefore **source** 5 V out of the
USB-C connector — the opposite of its normal role. If VBUS stays unpowered, the
radio never enumerates and there is no error, just silence.

### ⚠️ Measure before you modify — you probably don't need a solder mod

On the XIAO ESP32S3 the **`5V` pad and the USB-C VBUS pin are the same net**
(VBUS is pin 14 / the `5V` pad). The common, widely-used approach is simply to
**feed 5 V into the `5V` pad**; it reaches USB-C VBUS and powers the peripheral
with **no board modification**. Verify on your actual board first:

1. Multimeter, continuity mode: probe the `5V` pad against the USB-C shell/VBUS
   pin. ~0 Ω → the rail is already connected; inject 5 V on `5V` and you're done.
2. If instead you read a diode drop (~0.3 V) or an open, there is a series part
   in the path — identify its **exact designator from the official schematic**
   (Seeed wiki → Resources), confirm with the meter, then bridge that part.

> Earlier revisions of this note asserted an onboard Schottky diode always
> blocks the 5 V→VBUS direction. That is **not confirmed** for this board and is
> commonly the *opposite* of reality (the "diode" in Seeed forum threads is an
> **external** part you add to stop back-feeding when combining USB-C with an
> external 5 V source — an expansion-board concern). Trust the measurement + the
> schematic over any blog photo of a possibly-different revision.

### Options, in order of preference

1. **Inject 5 V on the `5V` pad** (after confirming `5V`↔VBUS continuity) —
   simplest, no mod. Power the XIAO from `5V`/`GND` (or `BAT`) and VBUS follows.
2. **Powered USB-C OTG cable / adapter** that injects external 5 V on VBUS —
   no board mod, no back-power hazard; good when you can't reach the `5V` pad.
3. **Bridge the in-path component** (only if step 1's measurement shows one, and
   only after identifying it on the schematic) so the `5V` rail feeds VBUS.
   ⚠️ **Then never power the XIAO from a PC and a bench/external 5 V supply at
   the same time** — that ties two 5 V sources together. Pick one source.

Note: this whole concern is really about the **bus-powered Yaesu** radios
(CP2105/CP210x). The **QMX is self-powered** over native USB, so it is unlikely
to depend on host VBUS at all — confirm per-radio at bring-up.

## Console & flashing (native USB is busy)

With USB-OTG in host mode, the USB-Serial-JTAG console/DFU is unavailable:

- **Console/logs → UART0:** `TX = GPIO43`, `RX = GPIO44`. Set
  `CONFIG_ESP_CONSOLE_UART_DEFAULT` (UART0) in sdkconfig; attach a 3.3 V USB-UART
  dongle. (These are the same pins the board labels TX/RX.)
- **Flashing:** hold **BOOT**, tap **RESET** to enter the serial bootloader,
  then flash over the UART0 dongle (`esptool`/`idf.py -p <uart> flash`). This
  keeps the radio cable untouched — the bench CI runner should use this path.
  Alternative for one-offs: unplug the radio and flash over native USB
  (BOOT+RESET → USB bootloader).

## Other pins used by the firmware

| Function | GPIO | Note |
|---|---|---|
| User LED | **GPIO21** | link-state signalling (`../implementation.md` §5.6). Active-low on XIAO. |
| UART0 TX | GPIO43 | console |
| UART0 RX | GPIO44 | console |
| BOOT btn | GPIO0 | bootloader entry |

## XIAO 14-pin header (for reference)

Standard XIAO pinout: 11 GPIO broken out plus `5V`, `GND`, `3V3`. Peripheral
defaults: I²C `SDA=GPIO5 / SCL=GPIO6`, UART `TX=GPIO43 / RX=GPIO44`, SPI
`SCK/MISO/MOSI` on the SPI block, 9× ADC. None of the header GPIOs are required
for the bridge beyond UART0 + the LED, leaving them free for future PTT/CW
line-level control if the app ever wants hardware keying.

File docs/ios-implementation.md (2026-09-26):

# CATBridgeKit — iOS Library Implementation Plan

## 1. Purpose and Scope

A Swift library (**CATBridgeKit**) that lets any iOS app control a transceiver
— **Yaesu FT-891, Yaesu FTX-1, QRP Labs QMX** — through the ESP32-S3 BLE↔USB
CAT bridge, and read its state.

The division of labor is fixed by the system design
(`esp32s3/docs/implementation.md` §1): the bridge is a dumb pipe; **all CAT
protocol knowledge lives here**. This library therefore owns:

1. The BLE link to the bridge (its GATT contract is normative in
   [`esp32s3/docs/protocol.md`](../esp32s3/docs/protocol.md)).
2. The bridge control plane (CTRL TLV, STATUS, failsafe, baud negotiation).
3. The CAT dialects (Yaesu ASCII for FT-891/FTX-1, Kenwood TS-480 subset for
   QMX) — command encoding, response parsing, polling.
4. A typed, observable transceiver model apps bind UI to.

Non-goals (v1): audio, waterfall/spectrum, rig memory management, CW paddle
timing (a system non-goal — see esp32s3 plan §1), multi-radio simultaneous
sessions, watchOS/tvOS, and **split/VFO-B operation** (state models VFO-A
only in v1; `IF;` already carries what a later split feature needs, so this
is scope control, not an architectural door closing).

**Platforms:** iOS 17+, macOS 14+ (macOS matters: it lets the entire test
suite run under `swift test` on CI without a simulator, and enables a future
Mac app for free). Swift 6 language mode, strict concurrency.

## 2. Idiomatic-Apple Ground Rules

What "as Apple pushes engineers to implement libraries" means concretely:

- **Swift Package Manager** package, no other distribution formats.
- **Swift 6 strict concurrency**: everything public is `Sendable`; mutable
  state lives in **actors**; UI-facing state uses **`@Observable`**
  (Observation framework) so SwiftUI views bind directly.
- **`async/await`** for commands; **`AsyncStream`/`AsyncSequence`** for
  continuous data (state updates, connection events, raw CAT taps).
- **Structured errors**: one `CATBridgeError` enum tree conforming to
  `LocalizedError`; no `NSError` bridging in the public surface.
- **Dependency inversion at the OS boundary**: CoreBluetooth is hidden
  behind a `BridgeTransport` protocol; the library never exposes `CBPeripheral`.
- **Swift API Design Guidelines** naming (`connect(to:)`, `setFrequency(_:)`,
  fluency at the call site).
- **DocC** documentation catalog with articles + tutorials; every public
  symbol documented.
- **Swift Testing** (`@Test`, `#expect`) — Apple's current test framework —
  not XCTest, except where XCTest is unavoidable (none anticipated).
- **`os.Logger`** with subsystem `radio.catbridge`, privacy-annotated.

## 3. Package Layout

```
(repo root)
├── Package.swift                  # swift-tools 6.0; iOS 17 / macOS 14
├── Sources/
│   ├── CATBridgeCore/             # ZERO-dependency pure logic (no CoreBluetooth)
│   │   ├── Ctrl/                  #   TLV codec, Status, opcodes  (protocol.md §2–3)
│   │   ├── CAT/                   #   dialects, parsers, values (Frequency, Mode…)
│   │   └── Session/               #   TransceiverSession actor, poller, cmd queue
│   └── CATBridgeBLE/              # CoreBluetooth transport (depends on Core)
├── Tests/
│   ├── CATBridgeCoreTests/        # unit + scripted-radio integration tests
│   └── CATBridgeBLETests/         # CB delegate plumbing tests w/ fakes
└── docs/
    ├── ios-implementation.md      # this file
    └── api-guide.md               # written at M4: integration guide for apps
```

Two targets on purpose: **`CATBridgeCore` must not import CoreBluetooth** —
that is what makes ~95 % of the library runnable under plain `swift test` on a
Linux-less macOS CI runner and in previews. `CATBridgeBLE` is a thin adapter.

## 4. Public API (the shape apps see)

```swift
import CATBridgeKit

// 0. ONE CBCentralManager for the process, owned by the library.
//    CoreBluetooth peripherals are only usable by the central that
//    discovered them, so scanning and connecting MUST share a central —
//    a scanner and a session with separate managers is a broken design.
let central = CATBridgeCentral()            // long-lived; app owns one

// 1. Discover bridges (each advertises the service UUID; protocol.md §1)
for await found in central.bridges() {      // AsyncStream<DiscoveredBridge>
    // found.name == "CATBridge-3F2A", found.rssi, found.id (UUID)
}

// 2. Connect — returns a ready session or throws a typed error.
//    Also accepts a persisted identifier (UserDefaults) for auto-reconnect
//    on later launches via retrievePeripherals(withIdentifiers:).
let session = try await central.connect(to: found)          // or (id: UUID)

// 3. Observe state (SwiftUI-ready)
@MainActor @Observable public final class TransceiverState {
    public private(set) var connection: ConnectionPhase
    public private(set) var radio: RadioModel?     // .ft891/.ftx1/.qmx/.generic
    public private(set) var frequency: Frequency?  // VFO-A, integer Hz core
    public private(set) var mode: OperatingMode?
    public private(set) var isTransmitting: Bool
    public private(set) var sMeter: SignalLevel?
    public private(set) var bridge: BridgeHealth   // baud, drops, fw, heap
}
session.state          // `nonisolated let`: reference from anywhere,
                       // property access on MainActor (where SwiftUI lives)
session.snapshots      // AsyncStream<TransceiverSnapshot> — an immutable
                       // Sendable VALUE copy per update, for non-UI consumers
                       // (never the mutable reference type across actors)

// 4. Control — async, throws, cancellation-safe
try await session.setFrequency(Frequency(hz: 14_250_000))
try await session.setFrequency(.megahertz(14.250))  // convenience; documented
                                                    // round-to-nearest-Hz
try await session.setMode(.cw)
try await session.transmit()               // failsafe interlock, §7.4
try await session.receive()
let freq = try await session.readFrequency()
try await session.send(keyerText: "CQ CQ DE …")   // where supported

// 4b. RF power, typed settings, menu items — no raw CAT required
try await session.setPower(watts: 50)             // validated per model
let watts = try await session.readPower()         // snapshot.power tracks it
try await session.set(.keyerSpeed, to: 25)        // RigSetting catalog:
let af = try await session.read(.afGain)          //   gains, squelch, NB/NR,
await session.supportedSettings                   //   preamp, atten, width …
await session.range(of: .afGain)                  // 0...255 (dialect-typed)
let v = try await session.readMenuItem("0301")    // Yaesu EX; raw digit value
try await session.setMenuItem("0301", value: "5")

// 5. Capabilities differ per radio — apps query, never guess
if session.capabilities.contains(.rfPowerControl) { … }
if session.capabilities.contains(.menuAccess) { … }     // Yaesu EX

// 6. Escape hatch for the remaining CAT surface: same serialization
let reply: Data = try await session.rawCommand("RM4;", expectsReply: true)
```

Design points:

- `TransceiverSession` is an **actor**. All radio I/O serializes through it —
  that is the concurrency model *and* the CAT correctness model (one in-flight
  command per radio; CAT has no framing to interleave replies).
- `TransceiverState` is `@MainActor @Observable`; the session publishes to it
  by hopping to the main actor per coalesced update. It is exposed as a
  `nonisolated let`, which is safe precisely because every property access is
  MainActor-gated. Cross-actor consumers use `snapshots` (immutable value
  type) — the mutable reference type never crosses an isolation boundary.
- `Frequency` stores **integer hertz** (`UInt64`) — CAT is integer-Hz on the
  wire and `Double` cannot represent 14.250 MHz exactly. Floating-point
  conveniences round to nearest Hz and say so in their docs.
- `TransceiverSession.init(transport: some BridgeTransport, …)` is **public**:
  it is how the test suite injects `ScriptedTransport`, and how an app could
  bring its own transport (e.g. a TCP link to rigctld) without touching BLE.
- Every control call is **cancellable** (Task cancellation propagates to a
  dequeued-or-abandoned command) and has a per-command deadline.
- `RadioModel` derives from the bridge's `STATUS.radio_id` (protocol.md §3),
  refined by the CAT `ID;` reply (`0650` FT-891, `020` TS-480-family QMX,
  FTX-1 TBD — see esp32s3 references). The dialect is selected internally;
  apps never handle dialects directly.
- `central.bridges()` returns a fresh single-consumer stream per call
  (AsyncStream semantics); scanning runs while ≥ 1 stream is active.

## 5. Architecture (layer by layer)

```
┌────────────────────────────  app (SwiftUI / UIKit)  ─────────────────────────┐
│   @Observable TransceiverState        async control methods                  │
├───────────────────────  TransceiverSession (actor)  ─────────────────────────┤
│  command queue (1 in-flight, timeout+retry policy)                           │
│  polling engine (IF; cadence, meters)     failsafe/PTT interlock             │
│  baud negotiation (ID; probe)             dialect selection                  │
├─────────────┬───────────────────────────────┬────────────────────────────────┤
│ CATDialect  │        BridgeControl          │   ResponseDemux                │
│ (Yaesu /    │  CTRL TLV encode/decode       │  ';'-scanner, garbage resync,  │
│  Kenwood)   │  STATUS decode, events        │  unsolicited (AI) handling     │
├─────────────┴───────────────────────────────┴────────────────────────────────┤
│                     BridgeTransport (protocol, Sendable)                     │
│   connect/disconnect · writeCAT · writeCtrl · inbound AsyncStreams · mtu     │
├──────────────────────────────────────────────────────────────────────────────┤
│  BLEBridgeTransport (CoreBluetooth)   │   ScriptedTransport (tests)          │
└──────────────────────────────────────────────────────────────────────────────┘
```

### 5.1 `BridgeTransport` (the seam that makes everything testable)

```swift
public protocol BridgeTransport: Sendable {
    var events: AsyncStream<TransportEvent> { get }   // connected, mtu, catData,
                                                      // ctrlFrame, status, disconnected
    func connect() async throws
    func disconnect() async
    func writeCAT(_ data: Data) async throws          // chunks to ≤ mtu-3 internally
    func writeCtrl(_ frame: Data) async throws        // with-response write
    var maximumCATWriteLength: Int { get async }
}
```

`BLEBridgeTransport` implements it with CoreBluetooth (§7).
`ScriptedTransport` implements it with the Swift port of the radio
personalities (§9.3). The session cannot tell them apart — by construction.

### 5.2 `BridgeControl` — the control plane (pure)

Direct Swift mirror of `esp32s3/test/tools/catproto.py` /
`firmware/components/ctrl_proto`:

- `CtrlFrame` encode/decode (`[op][len][payload]`, LE integers).
- Commands: `setBaud`, `getStatus`, `usbReset`, `setLine`, `purge`,
  `setFailsafe` — each paired with its ACK/NAK/answer rule (protocol.md §2:
  *exactly one reply per command*; GET_STATUS answers with its own opcode).
- `BridgeStatus` decode (22-byte versioned struct) with forward-compatible
  minor-version tolerance: unknown trailing bytes ignored, unknown
  `radio_id` mapped to `.unknown(rawValue:)`, version byte ≠ 1 → typed error.
- Events: `usbEvent(state:radio:)`, `overflow(direction:dropped:)`.

### 5.3 CAT dialects (pure)

```swift
protocol CATDialect: Sendable {
    var terminator: UInt8 { get }                 // ';' for all three
    func readFrequency() -> CATCommand            // encode side
    func setFrequency(_ f: Frequency) -> CATCommand
    func parse(_ response: ArraySlice<UInt8>, for: CATCommand) throws -> CATValue
    func parseUnsolicited(_ frame: ArraySlice<UInt8>) -> CATValue?
    var pttOn: CATCommand { get }                 // TX1; vs TX;
    var pttOff: CATCommand { get }                // TX0; vs RX;   (= failsafe string)
    var capabilities: RadioCapabilities { get }
}
```

- **`YaesuDialect`** (FT-891; FTX-1 subclasses/parameterizes it): 9-digit Hz
  `FA`, `MD0<code>;` with the newcat mode table, `IF;` fixed-width parse,
  `TX1;/TX0;/TX;`, `ID;`→`0650`, meters `SM0;`/`RM`. Mode codes are
  transcribed from `esp32s3/docs/references/yaesu-cat-ft891.md` (grounded in
  Hamlib `newcat_mode_conv[]`) — never from memory.
- **`KenwoodDialect`** (QMX): **11-digit** Hz `FA`, single-digit `MD`,
  `TX;`/`RX;` *without replies*, `ID;`→`020`, TS-480 `IF;` layout.
  QMX capabilities exclude what the radio lacks (e.g. `rfPowerControl`).
- Set-commands that produce **no reply** (both dialects) are modeled
  explicitly: `CATCommand.expectsReply == false` → completion is "bytes
  handed to transport", with the poller confirming effect on the next `IF;`.

### 5.4 `ResponseDemux` — stream discipline

CAT is a byte stream with a single `;` delimiter and **no correlation IDs**.
The demux:

- Accumulates transport bytes, emits `;`-terminated frames.
- **Garbage resync**: on frames failing dialect validation (baud mismatch
  produces binary noise), drop to the next `;` and count
  (`session.diagnostics.garbageFrames`); never crash, never wedge.
- Routes frames: if a command is in flight and the frame's prefix matches the
  expected reply → resolve it; `?;` → typed `CATBridgeError.radioRejected`;
  otherwise → `parseUnsolicited` (Yaesu Auto-Information, late replies after
  a timeout) → folded into state, never into the wrong continuation.
- A late reply arriving *after* its command timed out is recognized (prefix
  match against the last timed-out command within 1 s) and **discarded**, so
  it cannot resolve the *next* command with stale data.

### 5.5 Command queue policy

- One in-flight command; others await in an ordered queue inside the actor.
- Deadline: an **absolute per-command deadline** measured from write
  completion — 500 ms at ≥ 9600 baud, 1 s at 4800. Deliberately *not*
  "time since last transport activity": a radio chattering Auto-Information
  frames would reset an activity-based timer forever and wedge an unanswered
  command. Deadlines come from the injected `Clock` (§9.2), so tests are
  instant and deterministic.
- Retry: one retry for idempotent commands (all reads; frequency/mode sets).
  **Never retry** non-idempotent commands (`KY` keyer text, PTT transitions,
  anything via the raw escape hatch unless the caller opts in).
- **`?;` is not simply "invalid"**: Yaesu rigs also answer `?;` when busy.
  Policy (matching Hamlib's behavior): for an idempotent command, one delayed
  (50 ms) retry; if `?;` repeats, surface `.radioRejected`. Non-idempotent →
  surface immediately.
- Cancellation: a cancelled `Task` removes a queued command; an in-flight
  cancelled command is abandoned (reply discarded by the late-reply rule).
- `EVT_OVERFLOW` from the bridge (protocol.md §2): fail the in-flight
  command with `.bridgeOverflow`, purge demux buffer, let the caller/poller
  re-issue — mirrors the recovery contract in esp32s3 plan §6.

### 5.6 Polling engine

- Cadence: `IF;` at 2 Hz when idle, 5 Hz for 3 s after any set command
  (fast confirmation), plus `SM0;` at 2 Hz while receiving on radios with
  meters. All intervals are constants in one `PollingPolicy` struct —
  injectable for tests and app-tunable within bounds.
- Backs off automatically while a user command is queued (user > poller).
- Suspends when the app backgrounds without an active PTT (§7.4), resumes on
  foreground.
- **Auto-Information opt-in** (`PollingPolicy.enableAutoInformation`, off by
  default): on radios with the `.autoInformation` capability (Yaesu), the
  session sends `AI1;` at link init — and again after every reconnect — so
  the radio pushes state changes unsolicited. Pushes flow through the
  existing `parseUnsolicited` path into the same state/snapshots, giving
  near-instant frequency/mode updates with zero app-side change. Polling
  continues unchanged as the backstop (AI interleaves with replies and has
  rig-specific quirks; the poller also remains the only source on radios
  without AI). `disconnect()` best-effort restores `AI0;` so other CAT
  software isn't surprised later.

## 6. Connection Lifecycle & Baud Negotiation

State machine (surfaced as `ConnectionPhase` in state):

```
idle → scanning → connecting → discoveringServices → subscribing
     → bridgeReady            (STATUS read OK, fmt version check)
     → identifyingRadio       (radio_id + baud probe)
     → ready
any → reconnecting (backoff 0.5 s→8 s, jittered) → …
```

Baud probe on `bridgeReady` when `radio_id` is a CP210x profile
(FT-891/FTX-1; skipped for QMX — baud is cosmetic there):

1. `SET_BAUD 38400` → `ID;` (600 ms window) → hit? done.
2. else `SET_BAUD 9600` → `ID;` → hit? done.
3. else `SET_BAUD 4800` → `ID;` → hit? done; else surface
   `.radioNotResponding` with the bridge still `ready` (app shows guidance:
   check CAT RATE menu / cable).

`ID;` doubles as model confirmation; a mismatch between `radio_id` (transport
level) and `ID;` (protocol level) prefers `ID;` and logs the discrepancy.

CTRL deadlines: 1 s in general (`PollingPolicy.ctrlDeadline`), but `SET_BAUD`
and `SET_LINE` wait `usbControlDeadline` (6 s). Both make the firmware issue a
USB control transfer to the radio's serial chip; its host stack allows that
transfer 5 s and the bridge executes CTRL frames one at a time, so a slow
CP2105 (observed on the FT-891) holds every later reply behind it. A shorter
deadline never sped anything up — it desynchronised the walk, because the
late ACKs still arrived, and with the FT-891's rate at 4800 the step that got
skipped was the one that would have landed.

Late radio: when `STATUS` says no radio is enumerated, `start()` returns with
the session in `bridgeReady`. An `EVT_USB(enumerated)` later runs the same
identify sequence (line state → probe → failsafe → AI → poller) and emits
`.radioIdentified` on success or `.radioNotResponding` if the probe hears
nothing, leaving the phase at `bridgeReady`.

`CATBridgeCentral.connect` tears the BLE link down if `start()` throws. A
half-open link behind a discarded session is worse than none: the bridge stops
advertising, the app lists it as already connected while showing no session,
and the next attempt shares the peripheral with the abandoned one.

## 7. CoreBluetooth Specifics (`CATBridgeBLE`)

- **Write path**: CAT uses write-without-response, throttled by
  `canSendWriteWithoutResponse` / `peripheralIsReady(toSendWriteWithoutResponse:)`
  (the firmware assumes this — esp32s3 plan §6). CTRL uses write-with-response.
  Chunking to `maximumWriteValueLength(for: .withoutResponse)`.
- **MTU**: read from the peripheral after connect; the session's demux does
  not care (stream-oriented), but write chunking does.
- **Background**: `bluetooth-central` background mode documented as an
  *app-level* opt-in (Info.plist belongs to the app, not the library). State
  restoration via `CBCentralManagerOptionRestoreIdentifierKey` supported when
  the app passes a restoration ID into the `CATBridgeCentral` configuration.
  Restoration (and a few other CB behaviors) is iOS-only → those paths are
  `#if os(iOS)` and compile-checked by the CI simulator build (§9.5).
  Scanning by **service UUID** only (the firmware advertises it precisely so
  background scans work).
- **Bonding**: the firmware requires an encrypted link before CAT/CTRL writes
  (protocol.md §1). iOS surfaces pairing automatically on the first
  encrypted-characteristic access; the library maps the ATT
  insufficient-authentication error into `.pairingRequired` and retries once
  after pairing completes. "Peer removed bond" (firmware re-flashed) maps to
  `.bondInvalidated` with a recovery hint (Settings → Bluetooth → Forget).
- **No CB types in the public API.** `DiscoveredBridge` wraps identifier,
  name, RSSI.

### 7.4 PTT × app lifecycle

PTT is the safety-critical path (mirrors firmware §4.1/§5.5):

- **Arm-once, cached**: the session arms the dialect's failsafe
  (`SET_FAILSAFE "TX0;"` / `"RX;"`, ACK required) when the session reaches
  `ready`, and re-arms whenever the armed state could have been lost — after
  every BLE reconnect, after `EVT_USB(enumerated)` (firmware clears the
  failsafe on USB detach), and after any failsafe fire. `transmit()` then
  only checks the cached armed flag — **zero added latency per key-down**
  (arming per keying would cost a CTRL round-trip on every over).
- The interlock itself is not configurable and not bypassable: if the armed
  flag is unset (e.g. re-arm in flight after a reconnect), `transmit()` arms
  and awaits the ACK before keying; the raw escape hatch refuses PTT-on
  commands (matched against the dialect's encoding) while unarmed.
- `receive()` sends PTT-off and confirms via `IF;`/`TX;`. The failsafe stays
  armed while `ready` (it is idle-cost-free); it is *not* disarmed after each
  over, avoiding an arm/disarm churn window.
- If the app is backgrounded/suspended or the BLE link drops while
  transmitting, the **firmware** failsafe unkeys — the library's job is only
  the arm-before-key ordering guarantee above.
- A `pttWatchdog` (default 3 min, configurable 30 s–5 min, not off) sends
  PTT-off if the app forgets — belt to the firmware's braces. Firing is
  **loud, never silent**: state flips to `isTransmitting = false` with a
  `pttWatchdogTripped` entry in `session.events`, so a legitimate long
  transmission (WSPR is 2 min — the default must clear it) that trips the
  watchdog is visible to the app and the user, not a mystery unkey.

## 8. Error Taxonomy

```swift
public enum CATBridgeError: Error, Sendable {
    case bluetoothUnavailable(BluetoothUnavailableReason)  // off/unauthorized/unsupported
    case bridgeNotFound
    case connectionFailed(underlying: Error?)
    case connectionLost              // → session auto-reconnects; commands fail fast
    case pairingRequired
    case bondInvalidated
    case bridgeRejected(op: CtrlOp, code: CtrlErr)   // NAK passthrough, typed
    case bridgeOverflow(direction: OverflowDirection)
    case usbRadioDisconnected        // EVT_USB detached
    case radioNotResponding          // baud probe exhausted / poll silence
    case radioRejected(command: String)   // "?;"
    case malformedResponse(String)
    case timedOut(command: String)
    case unsupportedCapability(RadioCapability)
    case statusVersionUnsupported(UInt8)
}
```

Every case carries enough context to render user-facing guidance;
`LocalizedError` conformance supplies `errorDescription`/`recoverySuggestion`.

## 9. Testing Strategy

Layered like the firmware's (esp32s3 plan §7): everything below the
CoreBluetooth delegate line runs headless in CI; the thin CB layer is tested
with fakes; real-device checks are a scripted manual pass.

### 9.1 Unit tests (Swift Testing, `CATBridgeCoreTests`)

- **Wire-format golden vectors shared with the firmware — one file, not a
  comment**: a JSON vector file `esp32s3/test/vectors/ctrlproto.json`
  (frames, STATUS payloads, expected decodes) becomes the single source of
  truth. The Python suite loads it directly; the Swift package embeds a copy
  as an SPM resource (SPM cannot reference files outside the package root)
  and a CI step **byte-compares the two copies** — so the "duplicate" cannot
  drift silently, which a pinning comment never guarantees. Swift Testing
  consumes it via `@Test(arguments:)` over the decoded vector list.
- **Dialect encoders**: parameterized tests over the full mode tables (Yaesu
  newcat codes incl. `8`/`A`–`F` data modes; Kenwood single digits),
  frequency zero-padding at 9 vs 11 digits, boundary frequencies.
- **Dialect parsers**: `IF;` fixed-width parse for both layouts; `?;`; short/
  long/garbage frames; property-style fuzz (random bytes → parser never
  crashes, always resyncs).
- **Demux**: frames split across arbitrary chunk boundaries (1-byte drip,
  MTU-sized, straddling `;`), interleaved unsolicited frames, the
  late-reply-after-timeout discard rule.
- **BridgeControl**: TLV round-trips, truncated frames, unknown opcodes,
  status forward-compatibility (extra bytes / unknown radio_id).

### 9.2 Session integration tests (still headless, still fast)

`ScriptedTransport` drives the *real* `TransceiverSession` actor against
Swift ports of the three radio personalities from
`esp32s3/test/tools/radio_sim.py` (same command→response tables, same fault
injections — mute, stall-mid-response, garbage burst, disconnect). The port
is acknowledged duplication: it pins the radio_sim revision it mirrors in a
header comment, and the on-device rig (§9.4) runs against the *Python*
personalities, so a behavioral drift between the two shows up there rather
than never:

- Full connect → identify → ready flow per radio; dialect auto-selection.
- Baud-probe walk (38400 → 9600 → 4800) incl. all-fail surfacing.
- Command round-trips, no-reply set commands confirmed by next poll.
- Timeout → single retry → success; non-idempotent commands not retried.
- Cancellation: cancelled Task's command never sent / reply discarded.
- PTT interlock (§7.4): failsafe is armed (ACKed) before `ready`; the
  transport journal proves SET_FAILSAFE precedes the first PTT-on; re-arm
  happens after scripted reconnect and after `EVT_USB(enumerated)`; a
  `transmit()` racing an in-flight re-arm awaits the ACK before keying;
  raw-escape-hatch PTT while unarmed → throws.
- PTT watchdog: manual-clock advance past the deadline → PTT-off sent,
  `pttWatchdogTripped` event emitted (never a silent unkey).
- Overflow event → in-flight command fails, poller recovers state.
- Reconnect storm: scripted disconnects at every lifecycle phase; state
  machine always lands back in `ready` or a terminal error, never wedges.
- Deterministic time: the session takes a `Clock` (swift-clocks style
  injectable `any Clock<Duration>`); tests use a manual clock — **no
  `sleep`-based flakiness**.

### 9.3 BLE adapter tests (`CATBridgeBLETests`)

`BLEBridgeTransport` is written against tiny protocols
(`CentralManaging`, `PeripheralConnecting`) that `CBCentralManager`/
`CBPeripheral` conform to via extensions; fakes simulate delegate callback
sequences: connect flows, MTU values, notify delivery order,
`didUpdateValueFor` re-entrancy, write-without-response backpressure
(`canSend` toggling), state restoration payloads, ATT authentication errors.
This layer stays so thin that these tests are mostly plumbing-order checks.

### 9.4 On-device acceptance (manual, scripted checklist — `docs/testing-acceptance.md`)

With the real bridge + `radio_sim.py` rig (no radio), then real radios:

1. Discover, pair (bonded build), reconnect after app kill, after BT toggle.
2. Background: lock phone mid-poll → resumes; state restoration relaunch.
3. PTT on FT-891 into dummy load: key, kill the app mid-TX → **radio unkeys
   via firmware failsafe** (the system-level test that matters most).
4. Baud menu matrix on FT-891 (4800/9600/38400 CAT RATE).
5. QMX end-to-end: WSJT-X-style freq/mode flow.
6. Latency feel: frequency step scrubbing ≥ 5 cmd/s sustained.

### 9.5 CI

GitHub Actions `macos-latest`:

1. `swift build -c release` + `swift test` (Core + BLE fakes) — runs the
   whole headless suite natively on macOS.
2. **iOS simulator build** (`xcodebuild build -scheme CATBridgeKit
   -destination 'generic/platform=iOS Simulator'`): macOS-only compilation
   never touches iOS-only code (`#if os(iOS)` branches like CB state
   restoration — `CBCentralManagerOptionRestoreIdentifierKey` does not exist
   on macOS), so without this step those branches are unchecked until
   someone opens Xcode. Build-only; the fakes already test the logic.
3. Golden-vector byte-compare against `esp32s3/test/vectors/ctrlproto.json`
   (§9.1).
4. `swift package diagnose-api-breaking-changes` against the last tag once
   v0.1 is cut; DocC build with zero missing-symbol warnings.

## 10. Milestones

| # | Deliverable | Acceptance |
|---|---|---|
| M0 | Package scaffold, CI, DocC skeleton, error taxonomy | CI green on empty-ish package |
| M1 | BridgeControl (TLV/STATUS) + golden-vector tests | §9.1 control-plane tests green |
| M2 | Dialects + demux + parsers | §9.1 dialect/demux tests green |
| M3 | TransceiverSession actor + ScriptedTransport + personalities | §9.2 suite green |
| M4 | BLE transport + adapter tests + api-guide.md | §9.3 green; example SwiftUI app snippet compiles |
| M5 | On-device pass with bridge + radio_sim rig | §9.4 items 1–2, 6 |
| M6 | Real-radio pass (FT-891, QMX), failsafe kill-test | §9.4 items 3–5 |
| M7 | API review vs Swift guidelines, DocC tutorial, tag v0.1 | api-breaking-changes baseline |

## 11. Open Questions

1. FTX-1 `ID;` code and dialect deltas — blocked on hardware (same open
   question as firmware M7); `YaesuDialect` parameterization holds the slot.
2. Whether to expose a `Combine` bridge for legacy UIKit apps, or stay
   AsyncSequence-only (lean: stay async-only; Combine adapters are trivial
   for apps to write).
3. Minimum deployment: confirm iOS 17 floor is acceptable for the target
   apps; dropping to 16 forfeits `@Observable` (fallback: ObservableObject).
4. Localization of `LocalizedError` strings — ship English-only in v0.1 with
   String Catalog scaffolding?

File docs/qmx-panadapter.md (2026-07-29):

# QMX Panadapter — Implementation Plan

**Status:** proposed, nothing built · **Scope:** QMX only
**Supersedes:** the "waterfall/spectrum" v1 non-goal in
[`docs/ios-implementation.md`](ios-implementation.md) §1 — this is the v2 plan
for that feature.

## 1. Purpose

Put a live spectrum display and waterfall on the phone, fed by the QMX's raw
I/Q stream, over the existing BLE bridge.

Only the QMX can source this. It presents a composite USB device — CDC-ACM for
CAT **plus a USB sound card** — and the `Q9` CAT command switches that sound
card from demodulated audio to raw I/Q
(`esp32s3/docs/references/qmx-cat.md:15,105`;
`ios/pocket-cat-qmx/Sources/QMXKit/Menu/QMXMenuNotes.swift:96`). The FT-891 and
FTX-1 have no equivalent, so this feature is radio-specific by nature and stays
behind a capability probe.

### 1.1 What this does to the dumb-pipe principle

The system design fixes the bridge as a transparent byte pipe with all radio
knowledge in Swift (`esp32s3/docs/implementation.md` §1). DSP in firmware bends
that, so the split is drawn deliberately:

| Firmware owns | Because |
|---|---|
| USB audio transport, FFT, dB conversion, bin decimation | Sample-rate arithmetic, not radio semantics. Identical for any I/Q source. |
| Nothing about frequency, band, mode, or calibration | It doesn't know them, and must not learn them. |
| iOS owns | |
| Centre frequency, axis labels, span/zoom, dB calibration offset | The app already polls the VFO; the bridge would have to parse CAT to know it. |

Concretely: **spectrum frames carry no centre frequency.** They carry a sample
rate and bins of dBFS. The app labels the axis from the VFO frequency it
already tracks. That keeps the firmware ignorant of CAT, and means a future
I/Q source on another radio reuses the whole path unchanged.

## 2. Budget

At 48 kHz stereo 16-bit, raw I/Q is 1.54 Mbps — about 10× what BLE can
carry, so the decimation is not optional. **Expect 24-bit, not 16**: the
QMX's sound card streams 24-bit samples (it needs the dynamic range for
I/Q; QRP Labs documents 48 ksps 24-bit). That is 2.3 Mbps raw — still
trivial on USB, irrelevant to BLE (bins are 8-bit regardless), but the
DSP front end must ingest 3-byte packed samples from day one. Treat
16-bit as the *surprise* case, not the plan. Measured against a
conservative 100–300 kbps sustained notification budget (**to be verified on
hardware, not assumed**):

| Payload | Rate | Verdict |
|---|---|---|
| Raw 48 kHz I/Q | 1540 kbps | Impossible |
| I/Q decimated to 8 kHz complex | 256 kbps | Over budget, starves CAT |
| **256 bins × 8-bit @ 15 fps** | **~31 kbps** | **The design point** |
| 512 bins @ 20 fps | ~82 kbps | Upper end, needs measurement |

USB ingress is not a constraint: 1.54 Mbps fits full-speed 12 Mbps with room
to spare. Neither is CPU — a windowed 512-point complex FFT at 15 fps is a few
percent of one 240 MHz LX7 core with `esp-dsp`, against the ~90 FFTs/s the
sample rate would allow.

## 3. Protocol changes (normative — land in `esp32s3/docs/protocol.md`)

### 3.1 New characteristic

Base UUID `8f1dXXXX-52a4-4e1e-b34b-9d40b71d6e01`; `0001`–`0005` are taken
(protocol.md §1).

| XXXX | Name | Properties | Direction | Payload |
|---|---|---|---|---|
| `0006` | `SPECTRUM` | Notify | device → central | fragmented spectrum frames (§3.3) |

### 3.2 New CTRL opcode

| Op | Name | Payload | Errors |
|---|---|---|---|
| `0x07` | `SET_SPECTRUM` | `[enable:u8][bins:u16][fps:u8]` | `BAD_LEN`, `BAD_ARG`, `NO_USB`, `UNSUPPORTED`, `BUSY` |

- `enable = 0` stops streaming; remaining fields ignored.
- `bins` ∈ {64, 128, 256, 512}; `fps` ∈ 1–30. Anything else → `BAD_ARG`.
- `enable = 1` while already streaming is a **reconfigure**, ACKed, never
  `BUSY` — so the app can change bins/fps in one call without a
  stop/start glitch. (`BUSY` is reserved for a transient internal state,
  e.g. mid USB attach; the app treats it as retryable.)
- The firmware validates *achievability at the live ATT MTU* before
  ACKing: fragments per frame × fps must fit its notify budget. A 23-byte
  MTU asking for 512 bins @ 30 fps is `BAD_ARG`, not a silent stall —
  §3.3's "any MTU ≥ 32" is a statement about frame-format correctness,
  not throughput, and bench clients at default MTU would otherwise see a
  permanently blank waterfall.
- Streaming **auto-stops** on BLE disconnect and on USB detach. It is never
  persisted; a reconnecting central starts quiet.
- The `SPECTRUM` characteristic is notify-gated on subscription (the
  `status_subscribed` pattern in `ble_link.c`): no subscriber, no work.

**Capability discovery costs nothing new.** Firmware without the DSP path
answers `NAK` with `CTRL_ERR_UNSUPPORTED` — already defined at
`ctrl_proto.h:42` and currently unused. So the app probes by asking, and the
22-byte `STATUS` layout (protocol.md §3) does not change. No format-version
bump, no golden-vector churn on the existing status path. **The probe must
also treat `CTRL_ERR_UNKNOWN_OP` as "absent"** — that is what every
*currently shipped* firmware answers for opcode `0x07`, and it is the
answer the probe will actually meet in the field for the next year.

### 3.3 Frame format

Little-endian, consistent with §2. Fragment 0 carries the header; continuation
fragments carry only enough to place their bins.

```
frag 0 : [seq:u8][frag:u8=0][nfrags:u8][flags:u8][first_bin:u16]
         [bins_total:u16][sample_rate_hz:u32][bin bytes…]   header = 12 B
frag n : [seq:u8][frag:u8][nfrags:u8][first_bin:u16][bin bytes…]
                                                            header =  5 B
```

- `flags` is reserved (0 in v1) — one byte buys format evolution
  (averaged/peak-hold traces, 16-bit bins) without a new characteristic.
  Non-zero flags the decoder doesn't know → drop the frame, don't guess.
- Bins are **dBFS at 0.5 dB/LSB**: `0` = full scale, `255` = −127.5 dBFS.
  128 dB of range, more than the radio has. The dB reference is defined
  against a full-scale sine *after* the specified window (Hann) and FFT
  normalisation — pin this in the golden vectors or the synthetic-source
  tests will silently bake in whatever the first implementation did.
- Bin 0 is the lowest frequency of the window; **bin `bins_total/2` is DC**
  (even split: one extra bin below centre than above). Span is
  `sample_rate_hz`.
- **DC handling is mandatory, not cosmetic.** Direct-conversion I/Q has a
  DC offset that renders as a permanent fake carrier on the tuned
  frequency — the classic panadapter bug. The firmware subtracts the
  block mean before the FFT; the app may additionally interpolate the
  centre bin for display. Likewise assume **spectral inversion is
  possible** (I/Q swapped somewhere in the chain): verify against a known
  off-centre signal at M5 and, if mirrored, flip in `QMXKit` — never in
  firmware, which cannot know.
- `seq` is assigned **when a frame is generated, not when transmitted**,
  increments per frame, and wraps. Dropped frames therefore appear to the
  central as sequence gaps — that is the drop-reporting mechanism (§3.4).
- Frames are transmitted **atomically**: all fragments of a frame are
  handed to the stack back-to-back, and if any fragment's notify fails
  the remaining fragments are abandoned (the partial frame dies on the
  air). The central drops any incomplete frame; a `frag 0` bearing a new
  `seq` always resets reassembly, discarding whatever was pending.

At ATT_MTU 185, 256 bins is 2 fragments; at the negotiated 247 (the
firmware's `ATT_PREFERRED_MTU`) it is also 2. The *format* tolerates any
MTU ≥ 32; achievability at small MTUs is enforced at `SET_SPECTRUM`
(§3.2).

### 3.4 A deliberate exception to the data-path guarantees

protocol.md §4 currently states: *"BLE notify backpressure never drops (§5.1) —
bytes are retried."* **Spectrum inverts this.** The frame queue is depth 1–2
and drops the newest frame when full; frames are never retried and never
queued behind CAT.

This is a safety property, not an optimisation. The dead-man failsafe drops PTT
when the link goes quiet (protocol.md §2, failsafe semantics). A spectrum
backlog that delayed CAT or CTRL traffic could trip the failsafe mid-
transmission, or mask a real link loss. CAT always wins; a stale waterfall row
is worthless anyway.

**Dropped frames are reported by the `seq` gap alone — do NOT reuse
`EVT_OVERFLOW`.** An earlier draft proposed `EVT_OVERFLOW` with
`which = 2`; that is a live-fire bug against the shipped decoder:
`CtrlProtocol.swift:139` decodes *any* non-zero direction byte as
`.bleToUSB`, and the session's `handleOverflow` responds by resetting the
CAT demux and **failing the in-flight CAT command**
(`TransceiverSession.swift`, overflow path). Spectrum drops are routine
by design, so reusing the event would convert normal operation into a
stream of spurious CAT failures and user-facing "bridge dropped bytes"
notices. Sequence gaps carry the same information for free, per-frame,
with no rate limit and no cross-version hazard.

## 4. Firmware design

Two new components, following the repo's existing pure-vs-glue split
(`ctrl_proto` and `cat_bridge` are pure C and host-tested; `usb_link` is glue):

```
components/
  spectrum/      pure C: window → FFT → magnitude → dB → bin decimate →
                 fragment into frames.  No ESP-IDF dependency, host-tested.
  usb_audio/     glue: UAC host driver, isochronous IN, feeds spectrum/
```

- `spectrum` exposes a source-agnostic entry point taking a block of interleaved
  I/Q samples. `esp-dsp` supplies `dsps_fft2r` and the log table.
- `ble_link` gains the `0006` characteristic and the drop-newest queue.
- `ctrl_proto` gains `CTRL_OP_SET_SPECTRUM` and its validation.

**Build the synthetic source first.** A sweep/noise generator behind the same
interface as the real one lets the entire transport — protocol, firmware, Swift
decoder, UI — be built and tested with no radio attached, and gives CI
something deterministic to run. The real USB path then replaces the stub
without touching anything downstream.

## 5. The I/Q source (the unproven half)

### 5.1 Blocker: config descriptor size

`esp32s3/firmware/sdkconfig:2357` has `CONFIG_USB_HOST_CONTROL_TRANSFER_MAX_SIZE
= 256` (the IDF default, not overridden in `sdkconfig.defaults`). ESP-IDF
rejects any device whose **entire config descriptor** exceeds it
(`components/usb/enum.c:552-557`). A CDC-ACM + UAC1 composite — audio control,
two streaming interfaces with alt settings, format-type and AS-general class
descriptors — routinely lands at 250–400 bytes.

If the QMX crosses it, enumeration fails **before `on_new_device` runs**, so
`radio_detect` never executes and the app sees nothing at all — not even
`RADIO_UNSUPPORTED`. Raise it to 512–1024.

This is a one-line change that gates everything, **and it is not specific to
this feature**: if the QMX's sound card is present unconditionally, plain CAT
bring-up hits the same wall. Do it first regardless.

### 5.2 Coexistence with CDC

Should work, needs proving. The CDC driver claims only its two interfaces
(`cdc_acm_host.c:200,215`) and never issues `SET_INTERFACE` on the streaming
ones, so their alt≠0 isochronous endpoints are free for a UAC driver to claim.
The DWC host controller supports isochronous pipes (`hcd_dwc.c:1717`).
Espressif maintains a `usb_host_uac` component; version compatibility with the
pinned IDF (v5.3) is unverified.

**Confirmed gotcha (external):** UAC and CDC-ACM co-existing on one host
needs the UAC component's **`create_background_task = true`** — without it the
two functions fight over the host. Source: `SteffenLav/qmx-panadapter` (they
also patched the UAC component and pin ESP-IDF 5.4.4; we're on 5.3.5, so
budget time for a component bump or backport at M4). Their I/Q is **48 kHz
stereo**, matching §2. They also run a **Gram-Schmidt orthogonaliser** to
correct I/Q amplitude/quadrature imbalance — without it, ~30 dB mirror images
appear on the waterfall. Our firmware DSP does DC removal (§3.3) but no
imbalance correction; add it at M4 for image rejection, or accept mirrors in
v1. Their client retries the `Q9` handshake up to 4× at connect — `QMXKit`
now does the same (`QMXSpectrum.iqModeAttempts`).

Interface selection already handles compositeness correctly and is unit-tested
with a QMX-shaped fixture — audio on 0/1/2, CDC comm on 3, data on 4, asserting
`cat_iface == 3` (`esp32s3/test/host/test_radio_detect.c:53-69`).

### 5.3 Enabling I/Q, and its cost to the user

`Q9` is session-only and not saved to EEPROM (`qmx-cat.md:105-106`), so the app
must re-issue it after every radio power cycle, and on reconnect if the radio
may have been cycled.

**The tradeoff is real but narrower than it looks.** `Q9` streams I/Q
*instead of* demodulated audio on the same sound card. In the Pocket Cat
system, however, **nothing consumes that audio today** — the bridge does
not claim the UAC interfaces, and there is no host computer in the loop —
so flipping `Q9` costs the current user nothing. It matters in two future
cases: phone-side audio decoding (§10 non-goal) becomes impossible while
the panadapter runs, and a QMX later replugged into a PC mid-session
would hand WSJT-X I/Q instead of audio (self-healing on power cycle,
since `Q9` is session-only). Disclose the mode in the UI for honesty,
but don't architect around a conflict that doesn't exist yet.

Two operational details the app must own:

- **Re-issue and verify.** Reassert `Q9` on session ready and on every
  `usbRadioAttached` event (a radio power cycle drops USB, and the
  setting died with it) — and read `Q9;` back rather than assuming.
- **Transmit blanks the stream.** During PTT the RX chain's I/Q is not
  meaningful; the waterfall should visibly pause/grey during TX rather
  than paint junk rows into history.

## 6. iOS design

**Spectrum data must ride the `BridgeTransport` seam, not bypass it.**
The tempting shortcut — `CATBridgeBLE` publishing an
`AsyncStream<SpectrumFrame>` directly off the characteristic — cuts every
simulator out of the loop: `QMXSimTransport`, `FT891SimTransport`, and
the scripted test transports implement `BridgeTransport`, and anything
that doesn't flow through it cannot be faked, which forfeits the repo's
entire no-hardware test strategy (and M3). Instead: `TransportEvent`
gains a `.spectrumData(Data)` case (raw fragments), the **session** owns
reassembly and exposes `spectrumFrames() -> AsyncStream<SpectrumFrame>`
plus `setSpectrum(bins:fps:)`/`stopSpectrum()` beside its other typed
APIs. Thirty events/s through the session actor is noise next to its
per-command traffic. This also keeps the single-consumer `events` model
intact instead of inventing a second delivery path.

| Layer | Addition |
|---|---|
| `CATBridgeCore/Spectrum/` | `SpectrumFrame` + reassembly: fragment ordering, sequence gaps, flags check, drop-on-incomplete. Pure, headless-testable, **no CoreBluetooth** (ios-implementation.md §3). |
| `CATBridgeCore/Session` | `.spectrumData` transport event; `spectrumFrames()` stream; `setSpectrum`/`stopSpectrum` (CTRL); auto-`stopSpectrum` on `scenePhase` background is the app's job, but the session stops on disconnect for free. |
| `CATBridgeBLE` | Subscribe `0006`; forward fragments as `.spectrumData`. `BridgeGATT.swift` gains the UUID. |
| `CATBridgeCore/Ctrl` | `SET_SPECTRUM` encode + `UNSUPPORTED`/`UNKNOWN_OP` probe handling in `CtrlProtocol.swift`. |
| `QMXKit` | Panadapter policy: issue + verify `Q9`, re-issue on USB re-attach, map VFO frequency onto the axis, own the calibration offset and any spectral flip. `QMXSimTransport` gains a synthetic sweep source so previews/tests render with no hardware. |
| `QMXUI` | Trace view + waterfall; TX blanking; stop streaming when backgrounded (waterfalls in the background only burn the bridge's 500 mAh cell). |

Rendering: SwiftUI `Canvas` is adequate for a 256-bin trace at 15 fps. For a
scrolling waterfall with history, use a Metal texture and shift rows rather
than redrawing — the standard approach, and far cheaper.

Frequency labelling is the app's job (§1.1): it holds the VFO frequency, so
the axis is `vfo ± sample_rate/2`, adjusted for the offset the QMX applies in
I/Q mode. **RESOLVED (external): the QMX presents I/Q at +12 kHz IF** — the
stream's DC bin (frame centre) is `vfo + 12 kHz`, so the tuned signal sits a
quarter-span below centre. Source: the `SteffenLav/qmx-panadapter` project
(M5Stack Tab5 / ESP32-P4), which shifts bin selection by `n_bins/4` for the
same reason. Modelled in `QMXKit`'s `QMXSpectrum` (offset constant + bin↔Hz
mapping, unit-tested); the axis labels and VFO marker already use it. Confirm
the exact value against a real radio at M4. **Visually re-centring the trace
on the VFO** (vs marking it in place, which v1 does) is a real DSP/display
decision — the QMX baseband is asymmetric about the VFO (`vfo−12k…vfo+36k`),
so centring means cropping or panning; make that call against real I/Q at M4,
per the reference's `n_bins/4` crop.

Three labelling edge cases that will otherwise ship as bugs:

- **Retuning smears history.** Waterfall rows were captured at the old
  VFO; on QSY the app must either shift history horizontally by Δf (nice)
  or clear it (honest). Doing neither paints signals at frequencies they
  were never on — users notice immediately, especially while dragging the
  dial through a band.
- **RIT and split**: the axis should track the *receive* frequency
  (VFO ± RIT; VFO A vs B per `FR`), not blindly `FA`.
- **Display quality**: a single 512-point FFT per frame is visually
  noisy. Averaging 2–4 FFTs per emitted frame costs a rounding error of
  CPU (§2 headroom) and transforms the trace; make it the synthetic
  source's default so golden expectations include it.

## 7. Testing

Mirrors the existing strategy (`esp32s3/docs/implementation.md` §7):

- **Host C** (`test/host/test_spectrum.c`): windowing, FFT, dB conversion and
  bin decimation against golden arrays; fragmentation of every bin count at
  MTU boundaries; `SET_SPECTRUM` validation in `test_ctrl_proto.c` style.
- **Golden vectors**: add spectrum frames to `test/vectors/ctrlproto.json` and
  the Swift copy in `Tests/CATBridgeCoreTests/Resources/` in the same commit —
  CI byte-compares them, so they cannot drift.
- **Python** (`test/tools/`): `catproto.py` decodes the new frames;
  `ble_client.py` gains a `spectrum` subcommand for bench use.
- **Swift**: reassembly against gaps, duplicates, truncation, MTU changes.
- **HIL, the acceptance test that matters**: `soak.py` runs CAT polling *and*
  spectrum concurrently, asserting **CAT round-trip latency does not regress**,
  that frames drop (not queue) under induced backpressure, and — explicitly —
  that **the failsafe never trips** during a sustained spectrum + keyed-TX
  soak. That last assertion is the safety property §3.4 exists for; test it
  by name, not by implication.

## 8. Milestones

| # | Deliverable | Acceptance |
|---|---|---|
| M0 | Raise `CONFIG_USB_HOST_CONTROL_TRANSFER_MAX_SIZE`; confirm a QMX with its sound card active enumerates and CAT works | `EVT_USB` reports `QMX_CDC`; `ID;` round-trips on hardware |
| M1 | Protocol spec §3 changes; `ctrl_proto` opcode + host tests + vectors both sides | C and Python suites green; CI vector compare passes |
| M2 | `spectrum` component with synthetic source; `ble_link` characteristic and drop-newest queue | Host tests green; `ble_client.py spectrum` shows a moving sweep |
| M3 | Swift decoder + `AsyncStream`; QMXUI trace and waterfall against the synthetic source | Waterfall renders at 15 fps on device with no radio attached |
| M4 | `usb_audio`: UAC host claiming the streaming interfaces alongside CDC | Isochronous IN delivers samples while CAT stays up |
| M5 | `Q9` wiring in QMXKit, axis calibration, UI disclosure of the audio tradeoff | Real signals appear at the right frequencies on hardware |
| M6 | Measurement pass | Sustained fps and CAT latency under load recorded; battery life on the 500 mAh cell measured |

M1–M3 need no radio and no USB work. M4 onward is where the unknowns live.

## 9. Risks and open questions

| Risk | Impact | Mitigation |
|---|---|---|
| QMX config descriptor > 256 B | Total enumeration failure, silent | M0, before anything else — and the raise lands in `sdkconfig.defaults` (the checked-in source of truth), not the generated `sdkconfig` |
| 24-bit samples assumed late | DSP front-end rework | §2: plan for 3-byte packed from day one |
| DC spike / spectral inversion | Fake carrier at VFO; mirrored display | §3.3: mean-subtract in firmware; flip check at M5 in QMXKit |
| Small-MTU client requests unachievable bins×fps | Silent blank waterfall on bench tools | §3.2: `SET_SPECTRUM` validates against live MTU |
| Panadapter halves bridge battery | User surprise | §6 background auto-stop; publish the measured runtime in M6, in the README, next to the 500 mAh figure |
| `usb_host_uac` incompatible with IDF 5.3 or with a concurrent CDC claim | Kills the source; transport still usable with a stub | Prove in M4; the stub keeps M1–M3 shippable |
| QMX descriptor declares an unexpected rate/format | Rework of the DSP front end | Read the real descriptor early in M0 |
| iOS notify throughput below budget | Fewer bins or lower fps | `fps`/`bins` are runtime parameters; measure in M6 |
| Spectrum traffic delays CAT or trips the failsafe | Safety | Drop-newest, depth-1 queue, CAT priority; asserted in the HIL test |
| Continuous isochronous + DSP + BLE on a 500 mAh cell | Short battery life | Measure in M6; streaming is opt-in and auto-stops |
| I/Q not centred on the VFO | Mislabelled axis | Determine on hardware in M5 |
| Multiple CDC functions on the QMX ("COM port**s**", `QMXMenuNotes.swift:102`) | Wrong CAT interface chosen | Confirm at M0; `find_cdc_acm_comm` takes the lowest-numbered with no tie-break |

## 10. Non-goals

- **TX audio** phone → bridge → radio. The QMX accepts USB audio for SSB TX
  (`SS` command, `qmx-cat.md:63`); that is a separate feature with its own
  latency and safety analysis.
- **Phone-side demodulation** and decoding (FT8, CW). Narrowband I/Q at ~48
  kbps would make it possible and the frame format does not preclude it, but
  v1 ships magnitudes only.
- **Recording** or export of spectrum data.
- **FT-891 / FTX-1 support.** No I/Q source exists on those radios.

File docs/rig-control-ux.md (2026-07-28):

# Rig Control UX — Design Pass

**Status:** §4.1–4.3 built in both apps (band bar with stacking, memories,
recents); §3 and §4.4 still proposals, blocked on CAT formats this repo
does not yet document · **Scope:** `ios/pocket-cat-ft891` and
`ios/pocket-cat-qmx`

Three questions drive this: how to kill an unwanted whistle in one gesture,
how to hop around the band without thinking, and what iOS-native prior art
should shape both.

## 1. Where the interface stands today

| App | Receive controls | Band/frequency |
|---|---|---|
| FT-891 | `RXControlsDrawer` — a collapsed `DisclosureGroup` with AF/RF/squelch sliders and NB/NR/ATT/AMP toggles | digit-drag tuning, direct entry |
| QMX | AGC and filters only via the menu tree | digit-drag tuning, direct entry |

Two problems, both structural rather than cosmetic:

**Everything interesting is behind a disclosure triangle.** The controls you
reach for when a signal is unreadable are the ones that take the most taps to
find. A drawer is the right home for AF gain, which you set once; it is the
wrong home for a notch, which you reach for *because something is wrong right
now*.

**Nothing is spatial.** Shift, width, notch and contour all describe positions
and shapes in one frequency window, and four independent sliders throw that
relationship away. The operator has to hold the passband picture in their head
and translate it into four numbers.

### 1.1 What each radio can actually do

This is where the two apps stop being symmetric, and the design has to be
honest about it.

**FT-891** — the full Yaesu receive chain: IF shift (`IS`), width (`SH`),
manual notch (`BP`), contour (`CO`), auto-notch (DNF), NB, NR. The repo's CAT
reference (`esp32s3/docs/references/yaesu-cat-ft891.md:78`) is an explicit
subset and treats the rest as available — **the exact `BP`/`CO`/`IS` field
formats must be confirmed against the FT-891 CAT manual before any of this is
built.**

**QMX** — has no IF shift, no manual notch, and no contour. `FW` is
**read-only** (`qmx-cat.md:48`); filter selection lives in the `MM` menu tree.
So the passband editor below is an FT-891 feature. The QMX's answer to a
whistle is RIT, AGC threshold, a filter preset — and, once
[`docs/qmx-panadapter.md`](qmx-panadapter.md) lands, *seeing* the carrier.

Pretending otherwise would produce a QMX screen full of controls that do
nothing.

## 2. Prior art

### 2.1 What the leading iOS rig-control app does

[SDR-Control](https://documents.roskosch.de/sdr-control-ipad/) (Marcus
Roskosch) is the most mature iOS transceiver controller, in iPad and
[Mobile](https://documents.roskosch.de/sdr-control-mobile/) editions.

| Behaviour | Detail | Worth taking? |
|---|---|---|
| Double-tap the waterfall to QSY | "Double-tap somewhere on the waterfall to move the currently active VFO to that frequency" | **Yes** — the cheapest possible tune gesture |
| Drag the VFO line | "tap-and-hold the VFO Frequency (the yellow line) and move it left or right" | **Yes** — direct manipulation of the thing itself |
| Memories: tap to tune | "You can single tap to tune to a certain memory" | **Yes** — matches list-selection convention |
| Memories: `+` stores current | "the current frequency and mode settings can be stored using a desired memory name" | **Yes** |
| Filters behind a `FIL` button | "Tapping on the FIL button, you can select Filter 1 to 3" | **No** — presets, not a passband |
| Scrollable button bar | how the iPhone edition fits its controls | **No** — a wall of buttons is what we're avoiding |
| **No waterfall on iPhone** | "optimized for the small iPhone screen… use the iPad version… which offers additional features like displaying a Waterfall" | Instructive — see below |

**The most useful finding is a negative one.** Neither manual documents any
touch gesture for passband, shift, or notch adjustment. The leading app in
this category has not solved the problem this design is about, so there is
room to do it properly — and no established convention to violate.

Their iPhone edition dropping the waterfall entirely is a warning worth
heeding: a spectrum display that is too small to touch accurately is worse
than none. Our panadapter plan should treat the iPhone as the *primary*
target and design the touch targets first, not shrink an iPad layout.
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

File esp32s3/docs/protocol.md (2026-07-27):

# CAT Bridge BLE Protocol — v0.1 (normative)

The interface contract between the ESP32-S3 bridge firmware and any central
(the iOS app, `test/tools/ble_client.py`). Firmware and clients MUST be coded
against this document; changes land in the same PR as the firmware change
(docs/implementation.md §6).

Implementations: firmware `components/ctrl_proto` + `components/ble_link`;
Python reference `test/tools/catproto.py`.

## 1. GATT layout

Base UUID: `8f1dXXXX-52a4-4e1e-b34b-9d40b71d6e01`.

| XXXX | Name | Properties | Direction | Payload |
|---|---|---|---|---|
| `0001` | Service | — | — | primary service |
| `0002` | `CAT_RX` | Write, Write-No-Response | central → radio | raw CAT bytes, no framing |
| `0003` | `CAT_TX` | Notify | radio → central | raw CAT bytes, chunked ≤ ATT_MTU−3 |
| `0004` | `CTRL` | Write, Notify | both | TLV frames (§2) |
| `0005` | `STATUS` | Read, Notify | device → central | packed status (§3) |
| `0006` | `SPECTRUM` | Notify | device → central | fragmented spectrum frames (§6); absent on builds without the DSP path |
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

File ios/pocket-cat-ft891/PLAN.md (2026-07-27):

# FT-891 Pocket — Design, Implementation & Test Plan

An iOS app for full CAT control of the Yaesu FT-891 over the Pocket Cat BLE
bridge (`../..`, `CATBridgeKit`). Native SwiftUI, HIG-conformant,
iOS 17+.

Research grounding (read these first):
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

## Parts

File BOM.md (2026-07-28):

# PocketCAT — bill of materials

Quantities are per unit.

---

## Electronics

| Qty | Item | Key dimensions | Notes |
|---|---|---|---|
| 1 | Seeed XIAO ESP32S3 | 17.7 × 21.1 mm, USB-C overhangs 2.9 mm | No onboard antenna — the U.FL connector must be used |
| 1 | LiPo cell, 602535, 3.7 V 500 mAh | 25 × 37 × 6 mm | JST PH2.0 plug is cut off; leads solder to BAT+/BAT− |
| 1 | FPC antenna, 2.4 GHz | 37 × 18 mm | Ships with the XIAO. Mounts in the lid recess; pigtail is 1.13 mm coax |
| 1 | TPS61023 boost module | 17.8 × 11.3 mm | Adafruit MiniBoost clone. **Do not fit the pin header.** Any PCB thickness 0.6–1.8 mm is retained |
| **2** | Slide switch, SS12F15G5 | 19.8 × 5.6 × 13 mm | SPDT, 3-pin. S1 master, S2 mode. See below |

### Slide switch — SS12F15G5

| Parameter | Value | `.scad` parameter |
|---|---|---|
| Frame length, lug to lug | 19.8 mm | `sw_frame_l` |
| Mounting hole ⌀ | 2.2 mm | `sw_hole_d` |
| Mounting hole pitch | 14.4 mm nominal | `sw_pitch_spec` |
| Knob | 3.0 × 3.0 × 5.0 mm | `sw_act_l`, `sw_act_h` |
| Travel | 3.0 mm assumed | `sw_travel` |
| Body | 10.0 × 5.6 × 5.0 mm | — |

Sold in the same G5 variant by many suppliers, so the BOM is repeatable.

Two figures are not published by any seller and were scaled off the
manufacturer drawing: the **hole pitch** and the **travel**. The mount
does not depend on the pitch being right — see the peg pair in the README
— but if the knob binds at the ends of its throw, measure the travel and
reduce `sw_travel`.

---|---|---|
| Frame length, lug to lug | 19.05 mm (0.750″) | `sw_frame_l` |
| Mounting hole ⌀ | 2.37 mm (3/32″) | `sw_hole_d` |
| Mounting hole pitch | 14.82 mm | derived |
| Actuator | 6.16 × 4.3 mm | `sw_act_l`, `sw_act_h` |
| Body | 11.39 × 5.8 mm | — |

This part is not identified by manufacturer part number and may be hard
to re-source. **SS12F15G5** is a catalogued alternative in the same
family and is a reasonable substitute, but it is not a drop-in: its frame
is 19.7–19.8 mm, its holes are ⌀2.2 mm, and its actuator is a 3 × 3 × 5
mm knob with 3.0 mm travel. Switching to it requires updating
`sw_frame_l`, `sw_hole_d`, `post_d`, `sw_act_l`, `sw_act_h` and
`sw_travel`, then reprinting the base. Its hole pitch is not published —
measure before regenerating.

---

## Hardware

| Qty | Item | Notes |
|---|---|---|
| 1 | M3 × 10 hex socket head cap screw | M3 × 12 also fits |
| 1 | M3 nut, standard | 5.5 mm across flats, 2.4 mm thick |

No washer — the head seats in a counterbore inside the base.

---

## Printed parts

| Qty | File | Material | Solid volume | Mass |
|---|---|---|---|---|
| 1 | `pocket_cat_base.stl` | PETG | 11.05 cm³ | ~14 g |
| 1 | `pocket_cat_lid.stl` | PETG | 10.25 cm³ | ~13 g |

Roughly **23 g** of PETG per unit at 4 walls and 25 % infill, about 7.5 m
of 1.75 mm filament. No supports.

---

## Wire and consumables

| Qty | Item | Notes |
|---|---|---|
| ~600 mm | 22 AWG silicone stranded, 2 colours | 9 runs at ~60 mm; twist each pair. 26 AWG also fine and easier to route |
| — | Hot glue | Strain relief over the BAT+/BAT− joints |
| — | Cyanoacrylate | Fixes the switch to its pegs |
| — | Isopropyl alcohol | Prep the antenna bay floor before adhering |
| — | Kapton tape | Optional, only if the cell rattles |

---

## Interface

| Qty | Item | Notes |
|---|---|---|
| 1 | USB-C cable to the radio | Type and length depend on the transceiver's CAT port |

---

## Optional — RF mitigation

| Qty | Item | Notes |
|---|---|---|
| 1 | Clip-on ferrite for the USB lead | Against boost switching noise on HF |
| — | Copper foil tape | Line the lid over the boost, bond to battery negative |

---

## Wiring summary

| From | To |
|---|---|
| Cell + | Switch common |
| Switch output | XIAO BAT+ |
| Switch output | Boost Vin |
| Cell − | XIAO BAT− |
| Cell − | Boost GND |
| Boost 5V | XIAO VUSB |
| Boost GND | XIAO GND |

The switch sits upstream of both loads, so switching off also kills the
boost. That prevents the boost output back-feeding a host's VBUS when a
PC is plugged into the USB-C port to reflash.

Check whether En has a pull-up on your boost module. If not, tie it
to Vin.

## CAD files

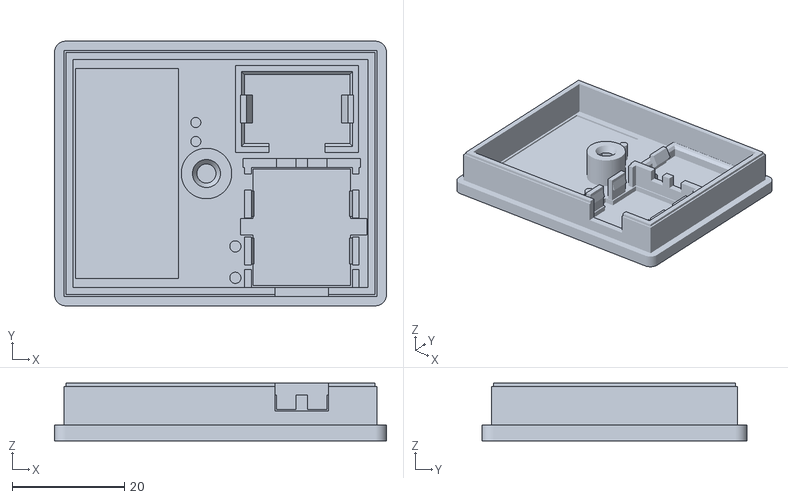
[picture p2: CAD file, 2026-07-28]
enclosure/pocket_cat_lid.stl
59.2 x 47.2 x 10.3

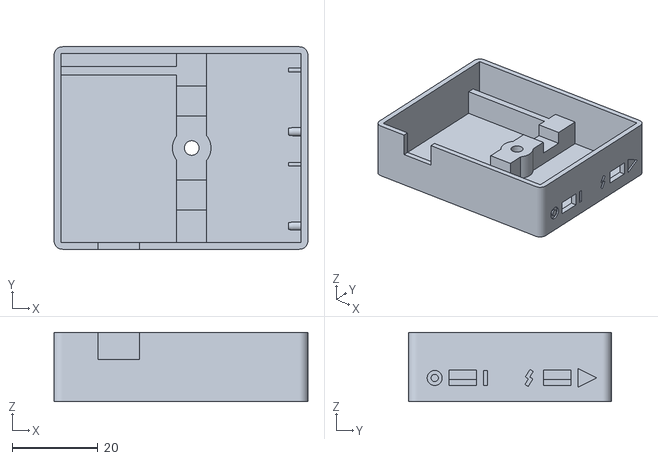
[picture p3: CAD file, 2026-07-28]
enclosure/pocket_cat_base.stl
59.2 x 47.2 x 16.1

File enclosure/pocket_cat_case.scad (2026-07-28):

// =====================================================================
// XIAO ESP32S3 BLE-CAT enclosure  --  v4
//
// Side-by-side bays, board on the lid, single central M3.
// Modelled in ASSEMBLED coordinates; print flip applied at export only.
//
// v4 changes (adversarial review):
//   CRIT-1  retention lips now ramped -- board can actually be inserted
//   CRIT-2  relief pocket in a 2.4 mm lid + taller seat = 2.6 mm over the
//           B+/B- solder joints (was 0.82)
//   CRIT-3  battery bay 7.0 -> 8.0 so the TPU pad stops eating the swell
//           allowance (was 0.00 spare, now 1.00)
//   MAJ-4   skirt_gap 0.2 -> 0.1, stepped lead-in on the skirt
//   MAJ-5   pcb_fit_y 0.30 -> 0.15, board Y slack 0.6 -> 0.3
//   MAJ-6   wire anchor posts on the lid
//   MIN     floor vents deleted, pry notches deleted, feed notch moved
//           clear of the bolt boss
//
// v5: bolt reversed. Enters from the base underside, head fully recessed
//     flush with the bottom face; nut is now captive in a boss on the lid.
//     Nothing protrudes from either outer face.
//
// Units: mm.  OpenSCAD 2021.01 or later.
// =====================================================================

/* [Part selection] */
part = "all";   // base | lid | lidasm | pad | assembly | all

/* [Battery - 602535 pouch cell] */
bat_x = 25;
bat_y = 37;
bat_z = 6;
bat_swell = 1.0;   // clearance ABOVE the cell

/* [Antenna - flat FPC] */
ant_x = 18;
ant_y = 37;
ant_fit = 0.4;      // recess clearance
ant_rec_d = 0.4;    // recess depth in the lid inner face

/* [Board - Seeed XIAO ESP32S3, measured] */
pcb_x = 17.7;
pcb_y = 21.1;
pcb_t = 1.2;
pcb_fit_x = 0.15;
pcb_fit_y = 0.15;
pcb_seat = 1.6;    // gap between PCB top face and lid inner face
lip = 0.5;         // retention lip, ramped
lip_h = 2.6;       // ramp height below the PCB - longer = shallower cam
rib_t = 1.2;       // pocket rib thickness - thinner = more compliant
tab_l = 5.0;       // length of each retention tab
slot_w = 0.8;      // relief slot isolating each tab
tab_y = [4.0, 12.4];  // tab start, local to the pocket
usbc_w = 9.0;
usbc_h = 3.2;
usbc_over = 2.9;
usb_clr = 0.3;

/* [Pad relief - clearance over the B+/B- solder joints] */
relief_inset = 0.3;  // relief now spans the WHOLE pocket, not a patch
relief_d = 1.2;
wire_y0  = 12.6;   // wire escape channel, lands inside existing slots
wire_y1  = 15.6;
wire_x0  = 3.5;
wire_x1  = 26.0;
// second gap, at the far end of the board, for the U.FL pigtail
coax_y0  = 20.9;
coax_y1  = 23.5;
coax_post_d = 1.8;   // guide posts for the pigtail run to the divider rib
coax_post_h = 4.0;
coax_post_x = 34.0;
coax_post_y = [29.3, 32.7];
// twin channels through the pocket end stop, for the boost-to-XIAO run
endch_w   = 3.5;    // each channel width
endch_gap = 2.0;    // web left between them

/* [Case] */
wall = 1.6;
floor_t = 1.6;
lid_t = 2.8;       // thickened to carry the relief pocket
rib = 7.0;
clr = 1.0;
corner_r = 2.0;
skirt_h = 7.5;     // deeper: buys headroom over the cell for the boost
rear_bay = 5.0;    // extra interior length for the boost module
skirt_w = 1.6;
skirt_gap = 0.1;
skirt_lead = 0.6;  // stepped lead-in at the skirt free edge

/* [Fastener] */
boss_d = 9.0;
bolt_d = 3.4;
nut_af = 5.6;
nut_t = 2.5;
nut_slot_w = 5.8;
head_d = 6.2;      // M3 socket head clearance
head_h = 3.0;      // counterbore depth in the base underside
lboss_d = 9.0;     // nut boss on the lid
lead_h = 1.5;      // conical lead-in for the bolt tip

/* [Boost module - TPS61023 MiniBoost clone] */
boost_l = 17.8;
boost_w = 11.3;
boost_t = 4.5;      // ESTIMATE: PCB + inductor, header off. Only sets the
                    // rib height; the bay clears up to 7.5 mm regardless.
boost_fit = 0.50;   // per side - 0.25 printed too close to fit
boost_rib_h = 2.5;
boost_rib_t = 1.6;
boost_gap = 10.0;   // opening in the pad-edge rib for solder access
// Compliant retention fingers. The retaining face is a wedge, not a
// square shoulder, so it clamps any PCB from boost_grip_min to
// boost_grip_max thick instead of needing one exact thickness.
boost_tab_w   = 5.0;
boost_tab_l   = 4.0;    // finger length below the lid inner face
boost_tab_t   = 1.0;    // finger thickness - thin so it flexes
boost_tab_gap = 0.4;    // relief each side of the finger
boost_tab_off = 0.15;   // finger face standoff from the board edge
boost_wedge   = 1.1;    // wedge protrusion - raised to match the looser pocket
boost_grip_min = 0.6;   // thinnest PCB the wedge will catch
boost_grip_max = 1.8;   // thickest

/* [Power switch - wall mounted in the antenna bay] */
// SS12F15 (SS12F15G5). Drawing tolerance is +/-5%, so the pitch is
// absorbed by the peg pair below rather than matched exactly.
sw_frame_l   = 19.8;    // overall length including the mounting ears
sw_frame_w   = 4.6;     // ear width
sw_pitch_spec = 14.4;   // hole centres - scaled off the drawing, not a spec
sw_hole_d    = 2.2;
sw_act_l     = 3.0;     // knob, along the travel axis
sw_act_h     = 3.0;     // knob, across
sw_travel    = 3.0;     // set to the measured throw once you have one
sw_slot_clr_l = 0.4;
sw_slot_clr_h = 0.6;
// Two switches. S1 is the master on/off; S2 selects run or charge.
// Off in S1 makes the illegal state (boost live with BAT connected)
// unreachable, and S2 being SPDT makes it exclusive by construction.
sw_cy        = [12.6, 34.6];
sw_cz        = 5.5;     // frame centre height above the base underside
post_d       = 1.90;    // round peg: locates the switch
post_tip_d   = 1.60;
post2_d      = 2.00;    // lozenge peg: full height across the pitch axis,
post2_tip_d  = 1.70;    //   narrow along it, so pitch error floats out
post2_y      = 0.90;
post_taper_l = 1.0;     // tapered lead-in
post_flat    = 0.15;    // shaved underside: pre-compensates for print sag
post_h       = 3.0;
// no skirt relief needed: the 4.6 mm frame and 5.6 mm body clear 8.60

/* [Panel markings] */
// IEC 60417: bar = on (5007), ring = off (5008). Drawn as primitives
// rather than text() so they do not depend on a font being installed.
mark_d    = 0.5;    // engraving depth
mark_h    = 3.5;    // symbol height / ring outside diameter
mark_w    = 0.9;    // stroke width
mark_gap  = 1.6;    // clear space between slot edge and symbol
mark_h_tri = 4.4;   // triangle drawn larger: it tapers, so it reads small
mark_flip = 0;      // set to 1 to swap which side gets the bar

/* [Feed line] */
feed_w = 7.0;
feed_d = 3.5;
feed_y = 34.0;

/* [Wire anchor] */
anchor_d   = 2.0;   // post diameter
anchor_gap = 3.6;   // clear channel - two 22 AWG silicone leads (~1.7 OD)
anchor_h   = 4.0;   // depth below the lid inner face
anchor_y0  = 5.0;   // first post centre

/* [Hidden] */
$fn = 64;
eps = 0.01;

// ---------- derived ----------
bat_bay_x = bat_x + 2*clr;
bat_bay_z = bat_z + bat_swell;              // 7.0
ant_bay_x = ant_x + 2*clr + 2.0;   // widened: the lid needs the span
inner_x   = bat_bay_x + rib + ant_bay_x;
inner_y   = max(bat_y, ant_y) + 2*clr + rear_bay;
inner_z   = bat_bay_z + skirt_h;
ext_x     = inner_x + 2*wall;
ext_y     = inner_y + 2*wall;
base_h    = floor_t + inner_z;
total_h   = base_h + lid_t;

lid_inner = base_h;
part_z    = floor_t + bat_bay_z;

pcb_cx    = wall + bat_bay_x/2;
pocket_x  = pcb_x + 2*pcb_fit_x;
pocket_y  = pcb_y + 2*pcb_fit_y;
pocket_x0 = pcb_cx - pocket_x/2;
pocket_y0 = wall + skirt_gap + skirt_w;

pcb_top   = lid_inner - pcb_seat;
pcb_bot   = pcb_top - pcb_t;
rib_bot   = pcb_bot - lip_h;

usb_w     = usbc_w + 2*usb_clr;
usb_bot   = pcb_bot - usbc_h - usb_clr;
usb_top   = pcb_bot + usb_clr;

sw_pitch  = sw_pitch_spec;
sw_wall_x = wall + inner_x;                               // inner face, +X wall
mark_s    = (mark_flip > 0) ? -1 : 1;
mark_half = (sw_act_l + sw_travel + sw_slot_clr_l) / 2;
mark_off1 = mark_half + mark_gap + mark_w/2;    // bar
mark_off2 = mark_half + mark_gap + mark_h/2;       // ring, bolt
mark_offt = mark_half + mark_gap + mark_h_tri/2;  // triangle

lboss_bot = part_z + 0.5;                 // lid boss reaches down to here
nut_bot   = lboss_bot + 1.5;              // pocket floor under the nut
nut_relief = lid_inner - (nut_bot + nut_t);   // stops at the lid inner face

bat_stop  = wall + 2*clr + bat_y;      // rear face of the cell pocket
ant_stop  = wall + 2*clr + ant_y;
boost_pl  = boost_l + 2*boost_fit;
boost_pw  = boost_w + 2*boost_fit;
ant_rec_w = ant_x + ant_fit;
ant_rec_l = ant_y + ant_fit;
ant_rec_x = (((wall + bat_bay_x + rib/2) + lboss_d/2)
              + (wall + inner_x - skirt_gap - skirt_w)) / 2
            - ant_rec_w/2;
ant_rec_y = wall + inner_y/2 - ant_rec_l/2;

boost_cx  = (wall + skirt_gap + skirt_w + wall + bat_bay_x) / 2;
boost_cy  = (pocket_y0 + pocket_y + 1.6 + wall + skirt_gap
             + (inner_y - 2*skirt_gap) - skirt_w) / 2;

boss_cx   = wall + bat_bay_x + rib/2;
boss_cy   = wall + inner_y/2;

skirt_ox  = inner_x - 2*skirt_gap;
skirt_oy  = inner_y - 2*skirt_gap;
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

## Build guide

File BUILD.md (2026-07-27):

# Building a Pocket Cat

Start-to-finish instructions for building one unit: a BLE↔USB CAT bridge in a
printed case, plus an iOS app to drive it.

Each step below says what to do, how to know it worked, and where the detail
lives. Follow them in order — the firmware is flashed **before** assembly,
because the board's programming pads face into the case once it's built.

| Step | You need | Detail |
|---|---|---|
| [0. Prerequisites](#0-prerequisites) | a Mac, a 3D printer, a soldering iron | — |
| [1. Buy the parts](#1-buy-the-parts) | a handful of parts, some slow to ship | [`BOM.md`](BOM.md) |
| [2. Print the case](#2-print-the-case) | PETG, ~23 g | [`enclosure/README.md`](enclosure/README.md) |
| [3. Flash the firmware](#3-flash-the-firmware) | USB-UART dongle | [`esp32s3/README.md`](esp32s3/README.md) |
| [4. Solder the wiring](#4-solder-the-wiring) | fine-tip iron, 26 AWG wire | [`enclosure/README.md`](enclosure/README.md#assembly) |
| [5. Assemble the case](#5-assemble-the-case) | M3 hex key | [`enclosure/README.md`](enclosure/README.md#assembly) |
| [6. Build and install the app](#6-build-and-install-the-app) | Xcode, an Apple ID | [`ios/`](ios/) |
| [7. First contact](#7-first-contact) | the radio | — |

Steps 2 and 3 need nothing from each other — print while you wait for parts,
and flash as soon as the board arrives.

---

## 0. Prerequisites

**Hardware you must already own**

- A 3D printer that can run PETG (or PLA — see step 2).
- A temperature-controlled soldering iron with a fine tip. The XIAO's BAT pads
  are small and lift if you dwell on them.
- A multimeter. Not optional: you will check the boost converter's output
  before it goes anywhere near the microcontroller.
- A Mac, for the iOS app. The firmware alone builds on Linux too.

**Software**

| Tool | For | Install |
|---|---|---|
| ESP-IDF ≥ 5.2 (CI uses 5.3) | firmware | [Espressif's getting-started guide](https://docs.espressif.com/projects/esp-idf/en/stable/esp32s3/get-started/) |
| Xcode 15 or later | iOS app | Mac App Store |
| `xcodegen` | generating the app project | `brew install xcodegen` |
| Python 3 + `pytest pytest-timeout pyserial` | firmware bench tools and their tests | `python3 -m pip install pytest pytest-timeout pyserial` |
| A slicer (PrusaSlicer, Cura, Bambu Studio, …) | the case | vendor site |
| OpenSCAD | *only* if you change the case dimensions | `brew install --cask openscad` |

After installing ESP-IDF, every new shell needs its environment:

```sh
. $HOME/esp/esp-idf/export.sh      # adjust to wherever you cloned it
```

**Checkpoint:** `idf.py --version` prints ≥ 5.2, `xcodegen --version` prints a
version, and `xcodebuild -version` prints Xcode 15+.

---

## 1. Buy the parts

Everything, with quantities, dimensions, substitutions and where to buy it, is
in **[`BOM.md`](BOM.md)**. The short version — one XIAO ESP32-S3, one 602535
LiPo cell, one TPS61023 boost module, one SS12F15G5 slide switch, an M3 bolt
and nut, and some 26 AWG wire.

Three things that trip people up, all covered in the BOM:

- The XIAO must be the version with the **U.FL antenna connector**. There is no
  onboard antenna; a board without it will advertise but barely reach across a
  desk.
- The boost module ships with a **pin header. Do not fit it** — the cradle in
  the lid has no room for it.
- You also need a **USB-to-UART dongle** to flash. It is not part of the
  finished unit, so it's easy to miss when ordering.

**Checkpoint:** parts on the bench, and the cell measures no more than 6 mm
thick. Thicker cells need `bat_z` changed and the base reprinted.

---

## 2. Print the case

Two parts, no supports:

- `enclosure/pocket_cat_base.stl`
- `enclosure/pocket_cat_lid.stl`

Settings: **PETG, 0.4 mm nozzle, 0.2 mm layer, 4 walls, 25 % infill.** About
23 g total, a few hours. Both parts are pre-oriented in the STLs — base floor
down, lid top face down. Slice as exported; do not rotate them.

PLA works if that's what you have, but the case sits in a bag with a battery in
it and PETG tolerates a hot car far better.

If you changed anything in `pocket_cat_case.scad`, regenerate first:

```sh
cd enclosure
openscad -o pocket_cat_base.stl -D 'part="base"' pocket_cat_case.scad
openscad -o pocket_cat_lid.stl  -D 'part="lid"'  pocket_cat_case.scad
```

Then clean up the two switch pegs on the base's right wall with a blade. They
print as horizontal features and sag slightly on their undersides — take
material off the bottom first. The switch frame should drop on without forcing.

**Checkpoint:** the lid's skirt slides inside the base walls, the switch frame
sits on both pegs, and the M3 nut slides into its slot in the lid boss.

Full printing notes, tolerances, and the parameter table for adjusting the fit:
[`enclosure/README.md`](enclosure/README.md#printing).

---

## 3. Flash the firmware

**Do this before soldering anything.** The XIAO's programming pads face into
the lid pocket once assembled, and the native USB-C port is used for the radio,
not for flashing.

Wire the USB-UART dongle to the board — three connections, and note TX goes to
RX:

| Dongle | XIAO ESP32-S3 |
|---|---|
| TX | GPIO44 (RX) |
| RX | GPIO43 (TX) |
| GND | GND |

Then build and flash:

```sh
cd esp32s3/firmware
idf.py set-target esp32s3
idf.py build
idf.py -p /dev/tty.usbserial-XXXX flash monitor
```

Find your port with `ls /dev/tty.usb*` (macOS) or `ls /dev/ttyUSB*` (Linux). If
flashing fails to start, hold **BOOT**, tap **RESET**, release BOOT — that
enters the ROM downloader — and run the flash command again.

Run the test suites too — they need no hardware:

```sh
make -C esp32s3/test/host run            # C: unit + end-to-end simulation
python3 -m pytest esp32s3/test/tools -q  # Python: codec, radio_sim, pty rig
```

**Checkpoint:** `idf.py monitor` shows the bridge booting, and the board
advertises as `CATBridge-XXXX` in any BLE scanner app.

Console details, the debug build without BLE bonding, and the
hardware-in-the-loop tools: [`esp32s3/README.md`](esp32s3/README.md).

---

## 4. Solder the wiring

Seven runs, about 60 mm each so the lid can lie flat for servicing. Twist each
pair tightly — loop area is what radiates into the receiver.

| From | To |
|---|---|
| Cell + | Switch common |
| Switch output | XIAO BAT+ |
| Switch output | Boost Vin |
| Cell − | XIAO BAT− |
| Cell − | Boost GND |
| Boost 5V | XIAO VUSB |
| Boost GND | XIAO GND |

The switch sits upstream of **both** loads. That is deliberate: switching off
also kills the boost, so its 5 V output cannot back-feed a host's VBUS when you
plug a PC into the USB-C port to reflash.

**Order matters, and one step is genuinely dangerous:**

1. **Cut the cell's JST plug off one lead at a time.** Cutting both at once
   shorts the cell through your cutters. A 500 mAh LiPo will happily weld them.
2. Solder the cell leads to BAT+ and BAT− on the underside of the XIAO, bend
   the wires flat immediately, and put hot glue over the joint. Those pads lift
   if a wire is ever tugged.
3. Wire the switch and the boost input.
4. **Before connecting the boost output to the XIAO**, switch on and measure
   the boost's output with your multimeter. It must read 5 V. If it reads 0 V,
   check whether `En` has a pull-up on your module — if not, tie it to Vin.
5. Only then solder boost 5V/GND to VUSB/GND.

**Checkpoint:** switch on, and the XIAO's LED lights and it still advertises
over BLE. Switch off, and everything goes dark — including the boost.

---

## 5. Assemble the case

Base first, then lid, then close:

1. Wipe the antenna bay with IPA and stick the FPC antenna down against its
   backstop rib.
2. Fit the slide switch on its two pegs, actuator through the slot, and glue.
3. Route the U.FL pigtail over the divider rib through the notch at y = 34.
4. Lay the cell in the left bay. **Do not glue it, and do not pack anything
   into the 1 mm space above it** — that's the pouch's swelling allowance. If
   it rattles, tape across it and stick the tape to the bay walls, never to the
   pouch.
5. Press the XIAO into the lid pocket, connector into the aperture first, then
   the rear edge past the retention ramps.
6. Press the boost module into its cradle, pad edge facing the board.
7. Dress the battery leads out through the wire channel and hook them round the
   anchor posts.
8. Lower the lid — the skirt slides inside the base walls — then fit the M3
   from underneath and snug it. **Snug only.** The skirt carries the shear; the
   bolt only resists lift.

**Checkpoint:** nothing protrudes from either outer face, the switch moves
through its full throw without binding, and the USB-C port is centred in its
aperture.

Numbered detail, the layout rationale, and what to change if a part doesn't
fit: [`enclosure/README.md`](enclosure/README.md#assembly).

---

## 6. Build and install the app

Pick the app for your radio:

| Radio | App |
|---|---|
| Yaesu FT-891 | [`ios/pocket-cat-ft891`](ios/pocket-cat-ft891) |
| QRP Labs QMX | [`ios/pocket-cat-qmx`](ios/pocket-cat-qmx) |

Both build the same way. Using the FT-891 app as the example:

```sh
cd ios/pocket-cat-ft891
swift test                       # headless tests, no hardware needed
cd App && xcodegen generate      # creates FT891.xcodeproj
open FT891.xcodeproj             # run the FT891App scheme
```

**You must set your own signing team.** Find your team ID:

```sh
security find-certificate -c "Apple Development" -p |
  openssl x509 -noout -subject | tr ',' '\n' | grep OU
```

In Xcode, select the app target → Signing & Capabilities → your team. Then run
to your iPhone with the device selected.

You can also install from the command line without opening Xcode:

```sh
xcrun devicectl list devices     # find your device's identifier
xcodebuild build -project FT891.xcodeproj -scheme FT891App \
  -destination 'id=YOUR-DEVICE-ID' -derivedDataPath build \
  -allowProvisioningUpdates DEVELOPMENT_TEAM=YOURTEAMID
xcrun devicectl device install app --device YOUR-DEVICE-ID \
  build/Build/Products/Debug-iphoneos/FT891App.app
```

**If signing fails on the iCloud entitlement** — "provisioning profile doesn't
match the entitlements file's values for the
`com.apple.developer.ubiquity-container-identifiers`" — your team has no iCloud
container for the app. Either add one in Xcode (target → Signing &
Capabilities → + iCloud), or build without it and let profiles fall back to
on-device storage:

```sh
CODE_SIGN_ENTITLEMENTS=FT891App/FT891App-NoCloud.entitlements
```

**Checkpoint:** the app launches and Connection → **Simulated FT-891** (or
Simulated QMX) runs the entire app with no hardware attached. Do this before
touching the radio — it separates app problems from link problems.

---

## 7. First contact

1. Plug the bridge into the radio's USB CAT port and switch the bridge on.
2. Open the app, and pair when iOS asks. Release firmware requires bonding
   before it accepts any CAT traffic.
3. The connection screen should report the radio it detected. The app probes
   the baud rate and picks the CAT dialect itself.

If it connects but shows no data, the usual causes are baud (the app probes
38400 → 9600 → 4800, but the radio's menu must be set to one of them), or the
radio's CAT port being the wrong one of two on an FT-891.

**If HF noise rises when the bridge is powered**, the boost converter is the
suspect: fit a clip-on ferrite on the USB lead, and consider lining the lid
over the boost with copper tape bonded to battery negative.

---

## Where things live

```
BOM.md              what to buy, and where
enclosure/          case: STLs, OpenSCAD source, print + assembly detail
esp32s3/            firmware: build, test, flash, bench tools
ios/pocket-cat-*/   the iOS apps
docs/               design plans and reports
```

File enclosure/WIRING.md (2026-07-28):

# PocketCAT — wiring

Two SS12F15G5 switches in series-with-mode arrangement. **S1** is the
master on/off; **S2** selects run or charge. Because S2 is SPDT, the boost
and BAT+ can never be live at the same time — the illegal state does not
exist in the wiring.

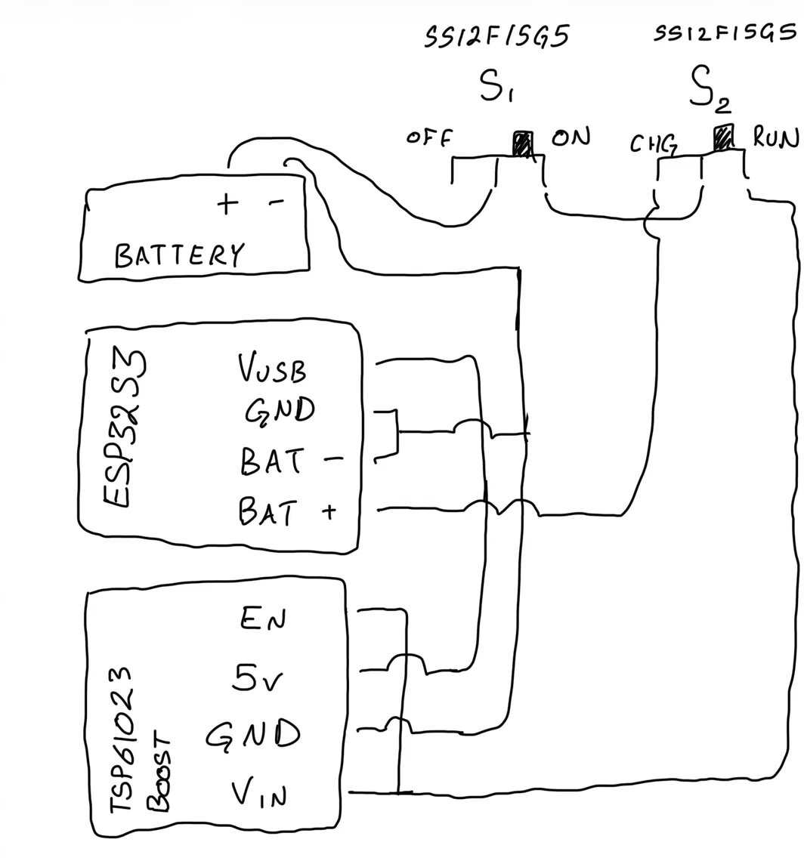
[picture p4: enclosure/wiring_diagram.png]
Hand-drawn schematic: the LiPo cell feeding S1 (off/on) then S2 (charge/run); the charge throw going to the XIAO ESP32S3's BAT+, the run throw to the TPS61023 boost Vin, and the boost 5V and GND returning to the XIAO's VUSB and GND


The sketch is the quickest way to see the topology; the
[connection table](#connections) below is the authority for what solders
to what. (The drawing letters the boost "TSP61023" — the part is the
**TPS61023**.)

```mermaid
flowchart LR
    subgraph BASE["BASE"]
        direction TB
        CELL["602535 LiPo<br>3.7 V · 500 mAh"]
        S1["S1 master<br>bar = on · ring = off"]
        S2["S2 mode<br>triangle = run · bolt = charge"]
    end

    subgraph LID["LID"]
        direction TB
        BOOST["TPS61023 MiniBoost<br>Vin · GND · 5V · En"]
        XIAO["XIAO ESP32S3<br>VUSB · GND · BAT+ · BAT-"]
        ANT["FPC antenna<br>37 x 18 mm"]
    end

    RADIO["Transceiver<br>USB CAT port"]
    CHG["USB charger or PC"]

    CELL -->|"cell + to S1 common"| S1
    S1 -->|"on throw to S2 common"| S2
    S2 -->|"run throw to Vin"| BOOST
    S2 -->|"charge throw to BAT+"| XIAO
    CELL -->|"cell - to GND and BAT-"| BOOST
    BOOST -->|"5V to VUSB"| XIAO
    BOOST -->|"GND to GND"| XIAO
    XIAO -.->|"U.FL pigtail"| ANT
    XIAO ==>|"USB-C: VBUS 5.2 V + data"| RADIO
    CHG -.->|"USB-C, charge mode only"| XIAO
```

## States

| S1 | S2 | Result |
|---|---|---|
| ring (off) | either | Cell fully isolated. True off. |
| bar (on) | triangle (run) | Boost powers the XIAO and drives VBUS for the radio. BAT disconnected, so the charger has nothing to loop into. |
| bar (on) | bolt (charge) | Cell on BAT+, boost dead. Plug the USB-C into a charger or PC to charge and reflash. |

All three reachable from outside the case.

## Connections

| # | From | To | Pair with | Notes |
|---|---|---|---|---|
| 1 | Cell **+** | S1 **common** | 4 | Cut the JST plug off |
| 2 | S1 **on throw** | S2 **common** | — | Both switches sit in the right bay |
| 3 | S2 **run throw** | Boost **Vin** | 4 | Crosses the divider rib at y 12.6 |
| 4 | Cell **−** | Boost **GND** | 3 | |
| 5 | S2 **charge throw** | XIAO **BAT+** | 6 | Crosses the rib at y 34.6 |
| 6 | Cell **−** | XIAO **BAT−** | 5 | |
| 7 | Boost **5V** | XIAO **VUSB** | 8 | VUSB is marked 5V on the top side |
| 8 | Boost **GND** | XIAO **GND** | 7 | Pin next to VUSB. Land both grounds on the boost pad, not chained through the XIAO |
| 9 | Boost **En** | Boost **Vin** | — | Short link on the module |

S1's second throw goes nowhere. That open position is the off state.

## Why BAT and VUSB must never both be live

VUSB is the VBUS node. The XIAO ESP32S3 carries a full battery management
system that starts charging whenever it sees USB power, and it cannot
distinguish the boost from a wall charger.

With the cell on BAT and the boost driving VUSB you get a loop —
cell → boost → charger → cell — through two conversion stages, bleeding
roughly 30–50 mA continuously while the cell never gains charge. Seeed
flag the same hazard from the other direction, recommending a blocking
diode when feeding the 5V/VBUS pin.

S2 makes this arrangement impossible rather than merely discouraged.

## Practical notes

**Twist every pair** per the table. Loop area is what radiates, and this
converter runs PFM at your load — bursty and variable-frequency, the hard
kind of noise to notch out of an HF receiver.

**Wire gauge.** 22 AWG silicone fits the anchors and channels. 26 AWG is
electrically ample — the boost draws about 160 mA at the input for a
100 mA CAT link — and routes far more easily in a case this size.

**Strain relief.** Hot glue over the VUSB, GND and BAT joints, then dress
the leads through the anchor posts. Those are surface pads with no
through-hole anchorage.

**En.** Tie it to Vin on the module. The clone may not carry Adafruit's
pull-up, and a floating enable on the TPS61023 is undefined.

**Output is 5.2 V**, deliberately high to offset cable drop. Within USB
tolerance at the far end.

## Routing through the case

| Run | Path |
|---|---|
| Cell + to S1 | Divider rib notch at y 12.6 |
| S1 to S2 | Along the right bay, no crossing |
| S2 run throw to boost Vin | Rib notch at y 12.6 |
| S2 charge throw to BAT+ | Rib notch at y 34.6 |
| Cell − to boost GND | Open space above the cell |
| Boost 5V and GND to XIAO | Twin end-stop channels at x 10.6–14.1 and 16.1–19.6 |
| Cell leads to XIAO | Wire escape channel at y 12.6–15.6, then the anchor posts |
| U.FL pigtail | Pocket gap at y 20.9–23.5, then the guide posts at x 34 |

Allow **60 mm** per run so the lid lies flat beside the base during
service.

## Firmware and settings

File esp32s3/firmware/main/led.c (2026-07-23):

#include "led.h"

#include "driver/gpio.h"
#include "freertos/FreeRTOS.h"
#include "freertos/task.h"

#define LED_GPIO 21 /* XIAO ESP32S3 user LED, active-low */

/* §5.6 patterns, sampled at 100 ms resolution over a 3 s cycle. */
static bool pattern_bit(bridge_t *b, uint32_t slot)
{
    uint8_t usb = atomic_load(&b->usb_state);
    bool ble = atomic_load(&b->ble_connected);

#if !CONFIG_BRIDGE_BLE_REQUIRE_BONDING
    /* Debug-open build: triple-blink burst overlay every 3 s (§5.6). */
    if (slot < 6) {
        return (slot % 2) == 0;
    }
#endif
    if (usb == (uint8_t)CTRL_USB_ERROR) {
        return (slot % 2) == 0; /* fast blink 5 Hz */
    }
    if (ble && usb == (uint8_t)CTRL_USB_ENUMERATED) {
        return true; /* solid: bridge live */
    }
    if (usb == (uint8_t)CTRL_USB_ENUMERATED) {
        return (slot % 10) < 2 && (slot % 10) != 1; /* double-blink-ish */
    }
    return (slot % 10) < 5; /* slow blink 1 Hz: idle */
}

static void led_task(void *arg)
{
    bridge_t *b = arg;
    uint32_t slot = 0;
    while (true) {
        gpio_set_level(LED_GPIO, pattern_bit(b, slot) ? 0 : 1); /* active-low */
        slot = (slot + 1) % 30;
        vTaskDelay(pdMS_TO_TICKS(100));
    }
}

void led_start(bridge_t *bridge)
{
    gpio_config_t cfg = {
        .pin_bit_mask = 1ULL << LED_GPIO,
        .mode = GPIO_MODE_OUTPUT,
    };
    gpio_config(&cfg);
    xTaskCreate(led_task, "led", 2048, bridge, 2, NULL);
}

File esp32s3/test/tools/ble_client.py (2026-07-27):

#!/usr/bin/env python3
"""ble_client — bleak-based reference client + BLE integration test driver
(docs/implementation.md §7.3). Doubles as the reference implementation of
the iOS app's transport layer.

Requires: pip install bleak   (and a BLE adapter on the test host)

Usage:
    ble_client.py scan
    ble_client.py status
    ble_client.py cat "FA;"                 # send one CAT command, print reply
    ble_client.py baud 38400
    ble_client.py failsafe "TX0;"
    ble_client.py echo --bytes 100000       # throughput/loss vs loopback rig
    ble_client.py storm --cycles 50         # connect/disconnect stress
"""

from __future__ import annotations

import argparse
import asyncio
import sys
import time

import catproto as cp

DEVICE_NAME_PREFIX = "CATBridge"
CAT_TIMEOUT_S = 0.5


class BridgeClient:
    """Async wrapper around one BLE connection to the bridge."""

    def __init__(self, address: str | None = None) -> None:
        self.address = address
        self.client = None
        self.cat_rx = bytearray()
        self.ctrl_rx = bytearray()
        self.ctrl_frames: list[cp.Frame] = []
        self.status: cp.Status | None = None
        self._cat_event = asyncio.Event()
        self._ctrl_event = asyncio.Event()

    async def discover(self) -> str:
        from bleak import BleakScanner

        dev = await BleakScanner.find_device_by_filter(
            lambda d, ad: cp.SVC_UUID.lower() in
            [u.lower() for u in (ad.service_uuids or [])]
            or (d.name or "").startswith(DEVICE_NAME_PREFIX),
            timeout=10.0,
        )
        if dev is None:
            raise RuntimeError("bridge not found (is it advertising?)")
        self.address = dev.address
        return dev.address

    async def __aenter__(self) -> "BridgeClient":
        from bleak import BleakClient

        if self.address is None:
            await self.discover()
        self.client = BleakClient(self.address)
        await self.client.__aenter__()
        await self.client.start_notify(cp.CHAR_CAT_TX, self._on_cat)
        await self.client.start_notify(cp.CHAR_CTRL, self._on_ctrl)
        await self.client.start_notify(cp.CHAR_STATUS, self._on_status)
        return self

    async def __aexit__(self, *exc) -> None:
        await self.client.__aexit__(*exc)

    # -- notification handlers --------------------------------------------

    def _on_cat(self, _h, data: bytearray) -> None:
        self.cat_rx += data
        self._cat_event.set()

    def _on_ctrl(self, _h, data: bytearray) -> None:
        self.ctrl_rx += data
        frames, rest = cp.decode_stream(bytes(self.ctrl_rx))
        self.ctrl_frames += frames
        self.ctrl_rx = bytearray(rest)
        if frames:
            self._ctrl_event.set()

    def _on_status(self, _h, data: bytearray) -> None:
        self.status = cp.Status.decode(bytes(data))

    # -- operations ---------------------------------------------------------

    async def cat_write(self, data: bytes) -> None:
        await self.client.write_gatt_char(cp.CHAR_CAT_RX, data, response=False)

    async def cat_command(self, cmd: str, timeout: float = CAT_TIMEOUT_S) -> bytes:
        """Send one ';'-terminated command; return bytes up to the next ';'."""
        self.cat_rx.clear()
        self._cat_event.clear()
        await self.cat_write(cmd.encode())
        deadline = time.monotonic() + timeout
        while b";" not in self.cat_rx:
            remaining = deadline - time.monotonic()
            if remaining <= 0:
                raise TimeoutError(f"no reply to {cmd!r}")
            try:
                await asyncio.wait_for(self._cat_event.wait(), remaining)
            except asyncio.TimeoutError:
                raise TimeoutError(f"no reply to {cmd!r}") from None
            self._cat_event.clear()
        return bytes(self.cat_rx)

    async def ctrl_command(self, frame: bytes,
                           timeout: float = 1.0) -> cp.Frame:
        """Send a CTRL frame; return its single reply frame (§4.1)."""
        want_op = frame[0]
        n_before = len(self.ctrl_frames)
        self._ctrl_event.clear()
        await self.client.write_gatt_char(cp.CHAR_CTRL, frame, response=True)
        deadline = time.monotonic() + timeout
        while True:
            for f in self.ctrl_frames[n_before:]:
                if f.op in (cp.Op.ACK, cp.Op.NAK) and f.payload[0] == want_op:
                    return f
                if f.op == want_op:  # GET_STATUS answers with its own opcode
                    return f
            remaining = deadline - time.monotonic()
            if remaining <= 0:
                raise TimeoutError(f"no ACK/NAK for op 0x{want_op:02x}")
            try:
                await asyncio.wait_for(self._ctrl_event.wait(), remaining)
            except asyncio.TimeoutError:
                raise TimeoutError(f"no ACK/NAK for op 0x{want_op:02x}") from None
            self._ctrl_event.clear()

    async def read_status(self) -> cp.Status:
        reply = await self.ctrl_command(cp.get_status())
        if reply.op != cp.Op.GET_STATUS:
            raise RuntimeError(f"unexpected reply {reply}")
        return cp.Status.decode(reply.payload)


# --- subcommands ------------------------------------------------------------

async def cmd_scan(_args) -> int:
    from bleak import BleakScanner

    print("scanning 10 s ...")
    for d in await BleakScanner.discover(timeout=10.0):
        print(f"  {d.address}  rssi={getattr(d, 'rssi', '?'):>4}  {d.name}")
    return 0


async def cmd_status(args) -> int:
    async with BridgeClient(args.address) as bc:
        st = await bc.read_status()
        print(st)
    return 0


async def cmd_cat(args) -> int:
    async with BridgeClient(args.address) as bc:
        reply = await bc.cat_command(args.command)
        print(reply.decode(errors="replace"))
    return 0


async def cmd_baud(args) -> int:
    async with BridgeClient(args.address) as bc:
        reply = await bc.ctrl_command(cp.set_baud(args.baud))
        ok = reply.op == cp.Op.ACK
        print("ACK" if ok else f"NAK err={cp.Err(reply.payload[1]).name}")
        return 0 if ok else 1


async def cmd_failsafe(args) -> int:
    async with BridgeClient(args.address) as bc:
        reply = await bc.ctrl_command(cp.set_failsafe(args.string.encode()))
        print("ACK" if reply.op == cp.Op.ACK else "NAK")
    return 0


async def cmd_echo(args) -> int:
    """Throughput/loss test against the loopback or radio_sim rig."""
    async with BridgeClient(args.address) as bc:
        payload = bytes(i & 0xFF for i in range(args.bytes))
        bc.cat_rx.clear()
        t0 = time.monotonic()
        for off in range(0, len(payload), args.chunk):
            await bc.cat_write(payload[off : off + args.chunk])
        while len(bc.cat_rx) < len(payload):
            before = len(bc.cat_rx)
            await asyncio.sleep(0.5)
            if len(bc.cat_rx) == before:
                break  # stalled
        dt = time.monotonic() - t0
        got = bytes(bc.cat_rx)
        lost = len(payload) - len(got)
        intact = got == payload[: len(got)]
        print(f"sent={len(payload)} recv={len(got)} lost={lost} "
              f"intact={intact} goodput={len(got) / dt:.0f} B/s")
        return 0 if lost == 0 and intact else 1


async def cmd_spectrum(args) -> int:
    """Panadapter bench view (docs/qmx-panadapter.md M2): enable the
    stream and print one ASCII trace line per frame."""
    async with BridgeClient(args.address) as bc:
        frames: list[cp.SpectrumFrame] = []
        reasm = cp.SpectrumReassembler()

        def on_spectrum(_h, data: bytearray) -> None:
            frame = reasm.ingest(bytes(data))
            if frame:
                frames.append(frame)

        await bc.client.start_notify(cp.CHAR_SPECTRUM, on_spectrum)
        reply = await bc.ctrl_command(
            cp.set_spectrum(True, args.bins, args.fps))
        if reply.op != cp.Op.ACK:
            print(f"NAK err={cp.Err(reply.payload[1]).name} "
                  "(old firmware or bad args?)")
            return 1
        deadline = time.monotonic() + args.seconds
        shown = 0
        glyphs = " .:-=+*#%@"
        try:
            while time.monotonic() < deadline:
                await asyncio.sleep(0.05)
                while shown < len(frames):
                    frame = frames[shown]
                    shown += 1
                    step = max(1, len(frame.bins) // 64)
                    row = "".join(
                        glyphs[min(9, (255 - frame.bins[i]) // 26)]
                        for i in range(0, len(frame.bins), step))
                    print(f"{frame.sequence:3d} |{row}|")
        finally:
            await bc.ctrl_command(cp.set_spectrum(False))
        lost = reasm.sequence_gaps + reasm.frames_dropped
        print(f"frames={shown} lost={lost}")
        return 0 if shown else 1


async def cmd_storm(args) -> int:
    """Connect/disconnect cycles; §7.3 requires advertising resume ≤ 2 s."""
    addr = args.address
    for i in range(args.cycles):
        t0 = time.monotonic()
        async with BridgeClient(addr) as bc:
            addr = bc.address  # reuse discovered addr for speed
            await bc.read_status()
        print(f"cycle {i + 1}/{args.cycles}: {time.monotonic() - t0:.2f}s")
    print("storm complete")
    return 0


def main() -> int:
    ap = argparse.ArgumentParser(description=__doc__,
                                 formatter_class=argparse.RawDescriptionHelpFormatter)
    ap.add_argument("--address", default=None, help="BLE address (else scan)")
    sub = ap.add_subparsers(dest="cmd", required=True)
    sub.add_parser("scan")
    sub.add_parser("status")
    p = sub.add_parser("cat")
    p.add_argument("command")
    p = sub.add_parser("baud")
    p.add_argument("baud", type=int)
    p = sub.add_parser("failsafe")
    p.add_argument("string")
    p = sub.add_parser("echo")
    p.add_argument("--bytes", type=int, default=100_000)
    p.add_argument("--chunk", type=int, default=180)
    p = sub.add_parser("spectrum")
    p.add_argument("--bins", type=int, default=256)
    p.add_argument("--fps", type=int, default=15)
    p.add_argument("--seconds", type=float, default=5.0)
    p = sub.add_parser("storm")
    p.add_argument("--cycles", type=int, default=50)
    args = ap.parse_args()

    handler = globals()[f"cmd_{args.cmd}"]
    return asyncio.run(handler(args))


if __name__ == "__main__":
    sys.exit(main())

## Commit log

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2026-07-23 Strengthen implementation plan after adversarial review
    Fixes factual errors and gaps found by attacking the plan:
    - CP2105 Enhanced (ECI) interface is #0, not #1; flag for empirical
    confirmation at first real-radio session
    - CP2102 breakouts (PID 0xEA60, single interface) cannot stand in for
    the FT-891's CP2105 (0xEA70, dual); test rig now uses a real CP2105
    for that path and keeps CP2102 as the generic-profile fixture
    - Default baud now 4800 to match FT-891 factory default; app owns
    baud probing/negotiation
    - BLE bonding is the release default (unauthenticated PTT of a 100 W
    transmitter is a safety issue), with a debug-only open mode and LED
    indication
    - New SET_FAILSAFE contro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
2026-07-23 Correct XIAO ESP32S3 VBUS guidance: measure before modifying
    The prior text asserted an onboard Schottky diode always blocks the 5V->VBUS
    direction, implying a solder mod is required for USB host power. That is
    unverified for this board and commonly the reverse of reality: on the XIAO
    ESP32S3 the 5V pad and USB-C VBUS are the same net, so injecting 5V on the 5V
    pad usually powers a bus-powered peripheral with no board modification. The
    'diode' in Seeed forum threads is typically an external part users add to stop
    back-feeding when combining USB-C with an external 5V source.
    - Lead the VBUS sections (implementation.md 2.1 and hardware reference) with a
    multimeter continuity check before an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
2026-07-23 Add Python test tools: radio_sim, ble_client, soak, shared catproto codec
    - catproto.py: TLV/STATUS codec + service UUIDs, mirrored from
    ctrl_proto.h with byte-exact wire-format vectors in tests
    - radio_sim.py: FT-891/FTX-1/QMX CAT personalities with per-character
    serial pacing and fault injection (mute, stall:N, garbage, split) for
    the 7.4 HIL rig; personality core is pure and unit-tested
    - ble_client.py: bleak reference client / integration driver (scan,
    status, cat, baud, failsafe, echo throughput, connect storm) per 7.3
    - soak.py: long-run IF; polling with STATUS anomaly detection per 7.6
    - 32 pytest cases green, including a real serial round-trip of serve()
    through a pty pair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
    [ble_client.py, catproto.py, radio_sim.py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]
2026-07-23 Add ESP-IDF firmware glue (usb_link, ble_link, main) and CI workflow
    - usb_link: usb_host lib + daemon task, CDC-ACM host driver with
    per-interface radio detection via new_dev callback, serialized
    open/close/reset link task, disconnect recovery with 3-failure
    backoff, CP210x setup via AN571 vendor requests (IFC_ENABLE,
    SET_LINE_CTL 8N1, SET_BAUDRATE, SET_MHS) so only the stable
    usb_host_cdc_acm ^2 component is a dependency
    - ble_link: NimBLE peripheral with the 4-characteristic GATT service
    (UUID base 8f1dXXXX-...6e01 shared with catproto.py), service UUID in
    the ADV payload, name in scan response, stop/resume advertising as the
    single-central policy, MTU + subscribe wiring,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
    [partitions.csv]
2026-07-23 Add normative BLE protocol spec (protocol.md v0.1) and esp32s3 README
    protocol.md freezes the GATT layout, CTRL TLV command/reply semantics,
    failsafe rules, STATUS format, and data-path guarantees now implemented
    by ctrl_proto/ble_link and mirrored in catproto.py (M2 deliverable).
    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
2026-07-23 Add iOS library (CATBridgeKit) implementation plan
    Swift package plan for controlling FT-891/FTX-1/QMX through the BLE
    bridge: two-target layout (pure CATBridgeCore + thin CATBridgeBLE),
    actor-based TransceiverSession with @Observable state, CAT dialects,
    response demux, failsafe-interlocked PTT, and a layered test strategy
    (golden vectors shared with firmware, scripted radio personalities,
    CoreBluetooth fakes, on-device checklist) with macOS-runnable CI.
    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
2026-07-23 Strengthen iOS library plan after adversarial review
    Fixes design bugs and gaps found by attacking the plan:
    - CoreBluetooth architecture: one shared CATBridgeCentral owns scan +
    connect (a CBPeripheral is only usable by the central that discovered
    it; the separate scanner/session managers in the draft were broken by
    construction); persisted-identifier reconnect via retrievePeripherals
    - Concurrency: never stream the mutable @Observable reference across
    actors — snapshots stream emits immutable Sendable values; state is
    @MainActor-isolated and exposed as nonisolated let
    - Failsafe: arm-once-and-cache at ready with re-arm on reconnect /
    EVT_USB / fire, instead of a CTRL round-tr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
2026-07-23 Implement CATBridgeKit iOS library with headless test suite
    Swift 6 package per iOS/docs/implementation.md:
    - CATBridgeCore (no CoreBluetooth): CTRL TLV codec + versioned STATUS
    decode with forward compatibility; Frequency (integer Hz); Yaesu and
    Kenwood dialects with Hamlib-grounded mode tables and IF parsers;
    ResponseDemux with garbage resync; TransceiverSession actor with
    FIFO command slot, absolute deadlines + idempotent-only retry, '?;'
    busy-retry, late-reply discard, baud probe (38400/9600/4800 via
    SET_BAUD + ID;), arm-once failsafe interlock, loud PTT watchdog,
    poller, reconnect backoff, MainActor @Observable state + snapshot
    and event streams
    - CATBridgeBLE (canImport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
    [test_catproto.py]
2026-07-25 Fix defects found in adversarial review of iOS + firmware
    iOS (CATBridgeKit):
    - CRITICAL: cancelling an in-flight command permanently deadlocked the
    session. withCheckedThrowingContinuation is never resumed on Task
    cancellation, so the continuation leaked AND the single command slot
    was held forever, hanging every subsequent command. Both the CAT and
    CTRL paths now use withTaskCancellationHandler; the cancelled
    command's reply prefix is recorded so a late reply is discarded
    instead of resolving the next command with stale data.
    - Unbounded leak: snapshots()/events() appended continuations to arrays
    that were never pruned, so every stream created (e.g. per view
    appearance) lea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
2026-07-27 Add typed power, settings, and menu APIs across FT-891, FTX-1, and QMX
    Apps no longer need raw CAT for the common rig surface:
    - readPower()/setPower(watts:) with per-model validation; snapshot.power
    filled at connect, kept fresh by setPower and Yaesu AI pushes
    - RigSetting catalog (AF/RF gain, squelch, mic gain, keyer speed,
    break-in, NB, NR, preamp, attenuator, narrow, filter width) with
    per-dialect wire tables, ranges, and per-setting feature detection
    - Yaesu EX menu access (readMenuItem/setMenuItem, .menuAccess capability)
    - QMX gains SM/PC/KS per qmx-cat.md's TS-480 subset (bring-up caveats
    noted where hardware limits are unconfirmed)
    Radio simulators (Swift + Python) answer t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
    [Pocket Cat.3mf, xiao_s3_base.3mf, xiao_s3_base.stl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]
2026-07-27 Assert DTR/RTS before the baud probe — FT-891 CAT RTS bring-up fix
    Found on real hardware: with menu 05-08 CAT RTS = ENABLE (the default),
    the FT-891 ignores every CAT byte until the host asserts RTS, so the
    session's ID; probe heard silence at all bauds and reported "no radio"
    with a healthy rig attached. The bridge's SET_LINE opcode existed end to
    end but nothing called it.
    The session now asserts DTR+RTS after USB enumeration (and again on USB
    re-attach, since the re-open loses line state) before any CAT traffic.
    Best-effort: radios that ignore line state (QMX CDC-ACM) are unaffected.
    Claude-Session: https://claude.ai/code/session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
2026-07-27 Add BOM, v5 enclosure, and hardware build docs
    Replaces the xiao_s3_* enclosure with pocket_cat_case.scad and its
    generated base/lid STLs (bolt reversed, captive nut in the lid, nothing
    protruding from either outer face). Drops the stale 3mf exports and the
    separate pad part.
    Adds BOM.md and expands the top-level README with what to buy and how to
    build a unit, including the USB-UART dongle needed to flash while the
    native USB-C port is in host mode.
    Claude-Session: https://claude.ai/code/session_017mJvcuT1cf9AbQ9BzmY2u9
    [Pocket Cat.3mf, pocket_cat_base.stl, pocket_cat_case.scad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]
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2026-07-27 Add the QMX panadapter implementation plan
    I/Q from the QMX sound card, FFT on the bridge, spectrum frames over a new
    BLE characteristic. Draws the firmware/app split so frames carry no centre
    frequency, inverts the never-drop data-path guarantee for spectrum so CAT
    and the PTT failsafe keep priority, and sequences the work so the transport
    is buildable against a synthetic source before any USB audio exists.
    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
2026-07-27 Panadapter plan: address adversarial-review findings
    - Replace the EVT_OVERFLOW which=2 reuse with seq-gap drop reporting:
    shipped clients decode any nonzero direction byte as .bleToUSB and
    fail the in-flight CAT command on every (routine) spectrum drop
    - Route spectrum through the BridgeTransport seam and the session so
    the simulators and the no-hardware test strategy keep working
    - Plan for 24-bit QMX samples; add flags byte to frag 0; define seq
    assignment, atomic frames, and frag0-resets-reassembly
    - Mandate DC removal, note spectral-inversion check, pin dB reference
    - SET_SPECTRUM: reconfigure semantics, MTU-achievability validation,
    UNKNOWN_OP probe compatibility with shipped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
2026-07-27 Docs: make the build path clear for builders
    Adds BUILD.md, a start-to-finish walkthrough (prerequisites, buy, print,
    flash, solder, assemble, install, first contact) with a checkpoint at each
    stage; the area READMEs stay the reference and gained the missing pieces.
    - BOM.md: repair the mangled slide-switch section, which contradicted the
    part the enclosure is actually dimensioned for; add where-to-buy guidance,
    and a tools list including the USB-UART dongle the BOM never listed.
    - esp32s3: prerequisites, UART dongle wiring, separate build/test/flash.
    - iOS: prerequisites, device install via devicectl, and the iCloud
    entitlement failure builders will hit.
    - enclosure: cut the JST lead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
2026-07-28 QMX: clock sync on connect and a WSPR beacon; both apps: keep-screen-awake
    Clock sync pushes the phone's UTC time to the radio on every connect (TM),
    recording how far out the radio was first. On by default, switchable.
    The WSPR beacon encodes callsign/grid/power to 162 channel symbols and
    clocks them out through TA — no audio path, because the phone times the
    symbols and the radio makes them. A 682.7 ms symbol makes BLE jitter
    irrelevant, and every symbol is pinned to an absolute deadline so jitter
    cannot accumulate across a frame. Frames are wrapped in transmit()/receive()
    so the bridge's dead-man failsafe and the 180 s PTT watchdog are armed:
    TA keys the radio, but the library only rec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
2026-07-28 Add a rig-control UX design pass
    Replaces four independent sliders with one spatial passband strip for the
    FT-891, a band bar with band-stacking as the fastest QSY, and device-side
    memories plus automatic recents. Records the prior art: SDR-Control's tune
    and memory gestures are worth copying, its filter presets are not, and
    neither of its manuals documents any passband gesture at all — Apple's own
    EQ and Camera interactions are the better model.
    Notes plainly that shift/width/notch/contour are an FT-891 story: the QMX
    has no manual notch and read-only FW, so its answer is the panadapter.
    Claude-Session: https://claude.ai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
2026-07-28 Bigger dial behind the label, with a finger dimple; add the passband build doc
    The dial now fills the tile and the label sits over it. The index bar is
    replaced by the finger dimple a real VFO knob carries — off-axis and inside
    the knob face, because a centred dimple reads as an eye.
    docs/passband.md is the build order for the passband strip, led by the
    unknowns: IS, BP and CO are absent from the repo's Yaesu reference and the
    per-mode SH width table does not exist yet. Those get answered on a bench
    and written back into the reference before any of the control is built.
    Claude-Session: https://claude.ai/code/session_017mJ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
2026-07-28 Outline the icon label; give the CW compose field a way out
    The label now draws a dark stroke pass under the white fill so it stands
    off the dial. Two passes rather than one stroked text because librsvg
    ignores paint-order and would otherwise paint the outline over the glyphs.
    The CW keyboard covered the tab bar with no way to dismiss it, which left
    the app stuck on that screen. Adds a keyboard-toolbar Done button, an
    interactive scroll-to-dismiss, and tap-the-transcript-to-dismiss.
    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
2026-07-28 QMX: split mode into family plus a REV toggle
    CW/DIGI/CW-R/FSK-R are two modes with two tone senses, not four peers.
    The strip now offers CW and DIGI plus a REV button that flips mark/space
    without leaving the mode — the A/B you actually perform while listening to
    something that tunes in but decodes as gibberish. Switching family keeps
    the current sense, so picking DIGI while reversed lands on FSK-R.
    The resolved MD code stays on screen so it is still obvious which of the
    four the radio is in.
    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
2026-07-28 QMX: query the radio's bands, and rework the CW compose bar after Dits
    The band bar now shows only the bands this unit has. Band config. is a
    grid with one column per band and a Band name (m) row; reading it at
    connect gives both the band list and each band's configured centre, which
    beats the plan's generic default as a landing frequency. An unreadable or
    unexpected menu leaves the list unknown and every band on show — hiding a
    band the operator owns is worse than showing one they don't.
    The CW compose bar borrows from Dits, minus anything needing audio:
    templates with {CALL}/{THEIRCALL}/{NAME}/{QTH}/{GRID} expansion, callsign
    chips spotted in the decoded copy for one-tap replies, repeat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
2026-07-28 QMX: station identity in Settings, WSPR as a tab, grid from GPS
    The CW templates pointed at Settings for a callsign, name, location and
    grid that Settings didn't have — a dead end. Those four fields now live in
    a Station section there, shared by the CW templates and the beacon, with a
    Use Current Location button that turns one CoreLocation fix into a
    six-character Maidenhead locator. WSPR sends the first four.
    WSPR is a tab alongside Operate and CW rather than a sheet behind a menu,
    and keeps only what is beacon-specific: power, band, interval, status.
    Claude-Session: https://claude.ai/code/session_017mJvcuT1cf9AbQ9BzmY2u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
2026-07-28 FT-891 Operate: stop the layout moving under the operator's thumb
    Keying swapped a one-bar S-meter for a three-bar TX cluster, reflowing
    everything below it — including the PTT button, at the exact moment it was
    being held. Both meter sets now live in one fixed-height panel that
    cross-fades, so keying changes what the screen says and never where
    anything is.
    The PTT also moves out of the scroll view into a pinned bottom inset: it
    can no longer be scrolled out of reach, and its press gesture no longer
    competes with the scroll view's. Frequency, mode, band, the RX drawer,
    Tune, Split and A/B are disabled while transmitting — changing band
    mid-carrier is at best pointless. RF power stays l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
2026-07-28 QMX: fix Start Beacon refusing a GPS grid, and tidy the WSPR station row
    wsprIsConfigured validated the raw grid, but GPS fills six characters and
    WSPR carries four — so the beacon start path squared the grid and the
    check didn't, and Start Beacon stayed grey with a perfectly good locator.
    A regression from adding GPS. The check now squares the grid exactly as
    the beacon does.
    The station section no longer shows a warning banner above the empty
    values it is complaining about: unset, it is one tappable row that opens
    Settings; set, it shows the values with an Edit in Settings button. The
    Start footer names the actual blocker — no radio, no callsign, an
    unparseable grid — because a disa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
2026-07-28 QMX Operate: fix the mode gap, make VFO a selector, and group the controls
    Mode was blank on connect because state.mode only fills after the
    library's first poll — the app now reads MD during refresh, and the chips
    are disabled rather than merely unlit until the mode is known. There is no
    way to deselect a mode because a radio always has one.
    REV and sideband both invert, at different layers, so two inversions
    cancel. Rather than leave that to be discovered on the air, the screen
    states the net result under the controls — including that REV plus LSB is
    the same as normal on USB.
    Split becomes one VFO selector — A / B / Split — which is how FR models it
    and makes clear that split is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
2026-07-28 Operate screen: stop the PTT jump, dock PTT, un-hide Receiver
    - Adopt MeterPanel (the fixed-height cross-fading slot that already
    existed for exactly this) so keying never reflows the layout; the
    DNF button moves into its RX side
    - Dock the PTT button in a bottom safeAreaInset with a bar background:
    the one safety-critical control never scrolls away and never moves
    under the operator's thumb
    - Receiver becomes an always-visible section with the same header
    treatment as Passband, values loaded on connect — it was the screen's
    only collapsed element, which read as arbitrary
    Claude-Session: https://claude.ai/code/session_014G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
2026-07-28 Hold-to-talk really holds: drive PTT from a button's press state
    The QMX transmit button was still inside the scroll view, so its
    zero-distance drag lost to the scroll pan and holding did nothing — my
    previous fix changed the gesture but left the button where the scroll view
    could take it.
    Both apps now dock the PTT outside the scroll view and drive key/unkey
    from a ButtonStyle's configuration.isPressed, which is the press state
    SwiftUI maintains itself: true from touch-down until the finger leaves,
    and not something an ancestor gesture can quietly win.
    Claude-Session: https://claude.ai/code/session_017mJvcuT1cf9AbQ9BzmY2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
2026-07-28 PTT: use onLongPressGesture, and show the press state separately
    onChange(of: configuration.isPressed) inside a ButtonStyle never fires:
    the style's body is rebuilt for each configuration, so onChange compares
    the new value against itself and sees no transition. That is why the
    previous fix changed nothing.
    Both apps now use onLongPressGesture(minimumDuration: .infinity), whose
    onPressingChanged is true from touch-down until release, on the view
    itself rather than inside a style.
    The button also reports its own press state — it dims, shrinks slightly
    and reads Keying… before the radio confirms with ON AIR — so a failure of
    the gesture and a failure of the CAT path can be told apart b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
2026-07-28 Fix the simulated QMX dropping out of transmit: IF flag block was short
    The TS-480 IF composite carries a five-character flag block between the
    RIT value and the TX flag — RIT-on, XIT, bank, and a two-digit channel.
    The simulator emitted four, so every field after it sat one place early
    and the parser read the mode digit as the TX flag. Keying set transmit
    optimistically, the next IF poll read '3' instead of '1', and the app fell
    out of transmit while PTT was still held: red header gone, button back to
    blue, PTT still down.
    This was also why the mode row was blank on connect — the parser was
    reading the character after the mode as the mode.
    Tests pin the offsets the parser actually use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
2026-07-29 Disconnect whenever there's a session, not only when it's ready
    The button was gated on the ready phase, so a connection that stalled
    mid-handshake offered no way out — which is when it is actually wanted,
    and why forgetting the device in iOS Settings became the workaround.
    It now appears for any live session, alongside a named connection state
    (Connecting…, Bridge ready — probing the radio…, Reconnecting (attempt 2)…)
    so a stall is legible rather than mute, and a footer noting that
    disconnecting lets the bridge advertise again.
    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
2026-07-29 FTX-1 support: enumerate the CAT chip behind the radio's internal hub
    The FTX-1 enumerates as a composite behind an internal USB hub
    (05E3:0610 → CP2105 10C4:EA70 + Yaesu HRI + C-Media audio), confirmed on
    hardware. Our USB host saw only the hub and reported UNSUPPORTED; the
    CP2105 CAT chip is one level down.
    - Enable CONFIG_USB_HOST_HUBS_SUPPORTED so the host enumerates through
    the hub, and fix CONFIG_USB_HOST_CONTROL_TRANSFER_MAX_SIZE=1024 (it
    never applied before — sdkconfig.defaults only seeds a fresh config)
    - usb_link: read usb_host_device_info parent to flag via_hub, skip the
    hub and a hubbed radio's non-radio siblings (audio/HRI) instead of
    reporting UNSUPPORTED and mask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
2026-07-29 Add the FTX-1 app
    Built from the FT-891 app, which the FTX-1 can share wholesale: it speaks
    the same modern Yaesu ASCII dialect, so operate, passband, band memories
    and connection plumbing carry over unchanged.
    Extended where the radio is: the full newcat mode set, since an FTX-1 is a
    full-mode SDR and the codes the FT-891 leaves unused — A DATA-FM, E C4FM,
    F DATA-FM-N — are live. A CW keyboard drives the memory keyer with station
    templates and an on-air estimate; it is send-only, because no Yaesu hands
    decoded CW back over CAT.
    Cut where the FT-891's knowledge does not transfer: its 159-item menu
    catalog and the profile engine built on it are gone, replaced by raw EX
    access by number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
2026-07-29 Panadapter: apply confirmed findings from SteffenLav/qmx-panadapter
    External validation from a working QMX panadapter (M5Stack Tab5 /
    ESP32-P4) resolves several of our open bench items:
    - QMX I/Q is at +12 kHz IF, not centred on the VFO. New QMXSpectrum
    models the offset (constant + unit-tested bin<->Hz mapping); the
    spectrum axis labels and the VFO marker now use it (marker sits a
    quarter-span in, not dead centre). Visually re-centring the trace is
    left as an M4 decision (the baseband is asymmetric about the VFO).
    - Q9 (I/Q mode) now retries up to 4x at connect and on USB re-attach,
    matching the reference client — it sometimes needs a couple of tries.
    - Documented for M4: the U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
2026-07-29 FTX-1: three-way preamp, power read at connect, live menu discovery, CAT console
    Preamp was a two-state toggle inherited from the FT-891, but PA0 takes
    0...2 and this radio has IPO / AMP1 / AMP2 — the command layer already
    allowed it, only the control couldn't reach the third.
    RF power was never read, so the slider sat on its default until dragged.
    The reply updates the session model, so asking is the whole fix.
    The Menu screen now discovers the radio's real menu: it walks a group's EX
    numbers, keeps what the radio answers and discards what it rejects, and
    remembers the result. The same approach the QMX app takes over MM, and the
    only honest one without a verified catalog. Menu is also r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
